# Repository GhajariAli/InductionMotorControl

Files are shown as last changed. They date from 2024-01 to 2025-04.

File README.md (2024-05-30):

# InductionMotorControl
Controlling 3 Phase AC Asynchronous Induction Motor

Check [This](https://github.com/GhajariAli/DCMotorControl) Repo for DC motor Control

<details>
<summary> Preparation </summary>
  
  <details>
    
  <summary> Motor Nameplate </summary>
  
  
  
  </details>
  
  <details>
    
  <summary> Designing the circuit </summary>
  
  I've Designed the control boad around this IC fro Infineon [IGCM04F60GAXKMA1](https://www.digikey.ca/en/products/detail/infineon-technologies/IGCM04F60GAXKMA1/5960098)
  
  Here is the video of testing the circuit and getting initial result:
  
   (https://www.youtube.com/shorts/fg0to3o2meA)
  
  So I designed a PCB to get things going Faster, you can find the KiCAD design and initial code to run the motor in [THIS](https://github.com/GhajariAli/InductionMotorControl/tree/FirstCurcuitDesign) branch
  
  
  
  
  
  
  
  </details>
  
  <details>
    
  <summary> Adding Encoder </summary>
  Induction Motors are usally not controlled by a closed loop using encoder but to validate and verify my own work I'd like to have and encoder on the shaft.
  
  [here](https://www.aliexpress.com/item/4000094589182.html?spm=a2g0o.order_list.order_list_main.56.1fdd1802ZbFUS8) is the encoder I've used : 
  
  (https://www.aliexpress.com/item/4000094589182.html?spm=a2g0o.order_list.order_list_main.51.55f218029jO34n)
  
  Below is what I've designed to mount the encoder, you'll find all 3D models in the same branch as mentioned in the circuit diagram section.
  
  
  
  
  
  Update: had to dessign and print the belt with TPU as it was not standard size turned out good:
  
  
  </details>

  <details>
    
  <summary> Testing the PCB </summary>
  PCB came very good. had to change couple resistors and design a base for it:
  
  

  
  
  and IT WORKS THE FIRST TRY!
  </details>
</details>

<details>
<summary> SPWM speed Control </summary>
  Here is the low and high side signals with only Hi side SPWM:

  

  and here is the final output 3phase
  
  

  this made the motor run smoother, current is now lower and it makes less noise.
  
  This was great but the curent of the motor was not sinusoidal at all.

  Terrible waveform:

  

  the reason is behind this picture
  
  
  
  so the high and low are not equal value. So it's required to add low side SPWM as well
  Here is the gate signals with all SPWM
  
  
  
  A Closer look
  
  

  Here is how the SPWM signals on the High side look after passing through a Filter:
  
  

  Now motor current is much more close to sinusoidal current
  
  

  here is how the syncronous speed, actual speed and slip looks like in a ramp to 50HZ and coast to stop. as you can see it's not great yet, need to source more voltage (currently only have 60VDC), I believe the V/F control can't go all the way to 50hz with 60 volt.

  

</details>

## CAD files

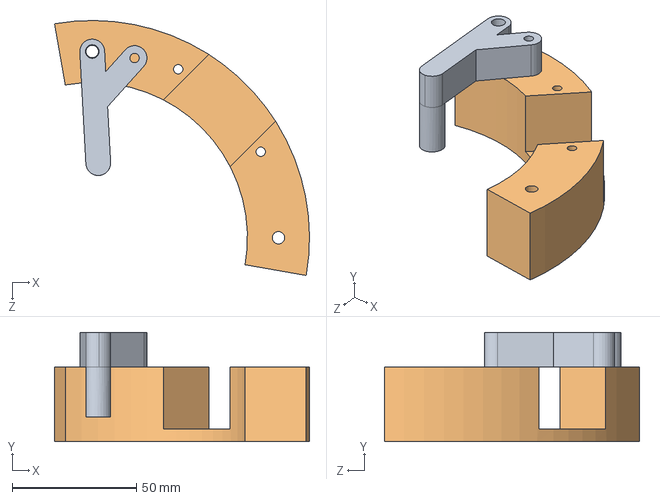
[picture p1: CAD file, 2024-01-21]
3D Models/Encoder.SLDASM
102.7 x 44.0 x 102.7 mm
Encoder Bracket
tensioner

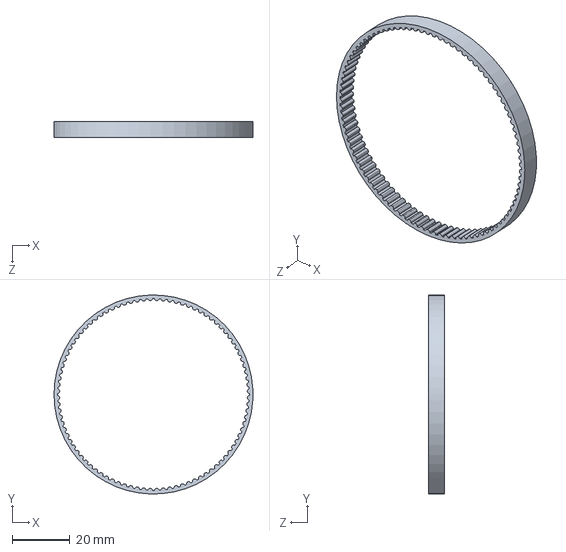
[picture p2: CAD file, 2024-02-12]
3D Models/belt.SLDPRT
69.0 x 69.0 x 5.50 mm

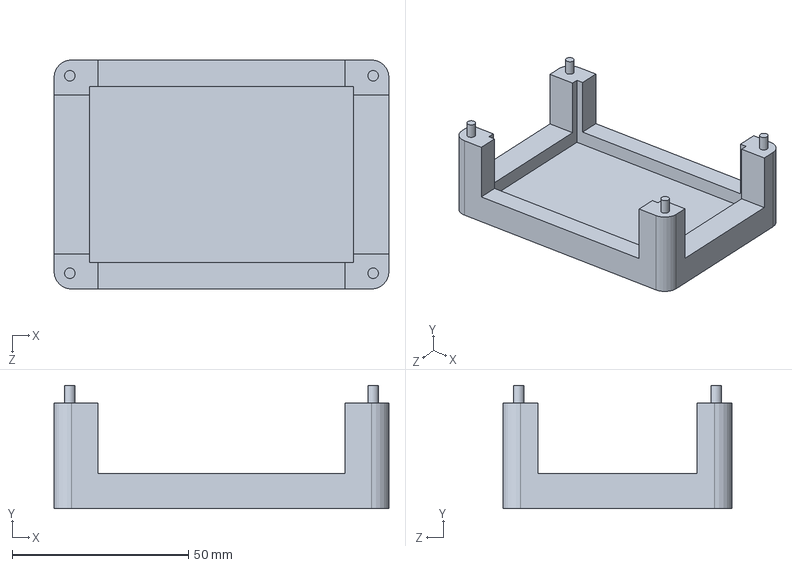
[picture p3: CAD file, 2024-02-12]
3D Models/base for board.SLDPRT
95.0 x 35.0 x 65.0 mm

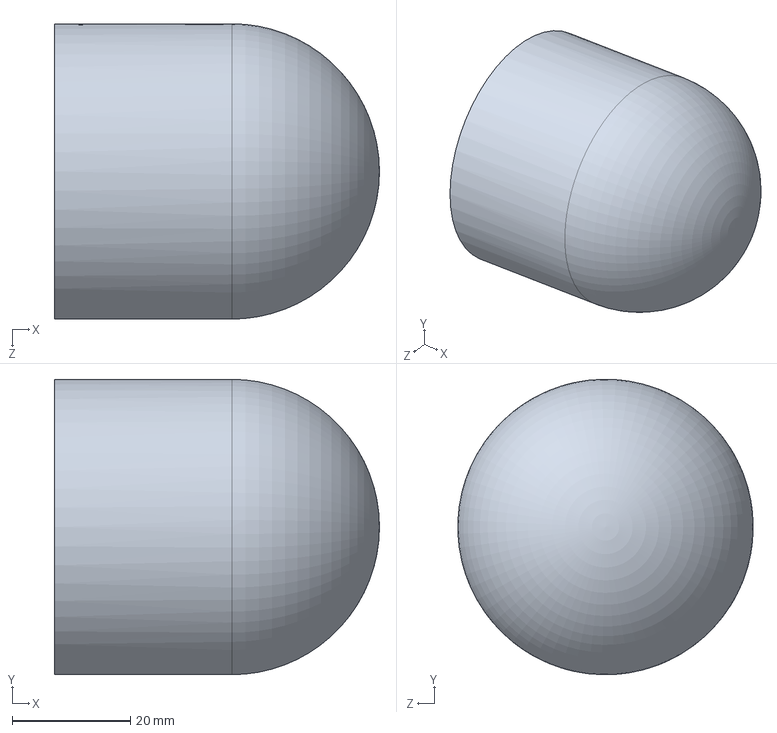
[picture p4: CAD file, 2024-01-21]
3D Models/ShaftFist.SLDPRT
55.0 x 50.0 x 50.0 mm

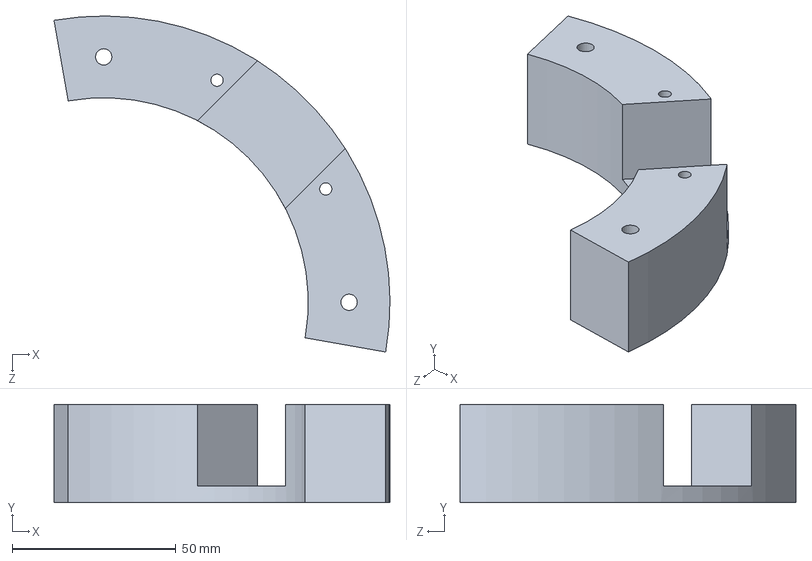
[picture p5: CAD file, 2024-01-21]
3D Models/Encoder Bracket.SLDPRT
102.7 x 30.0 x 102.7 mm

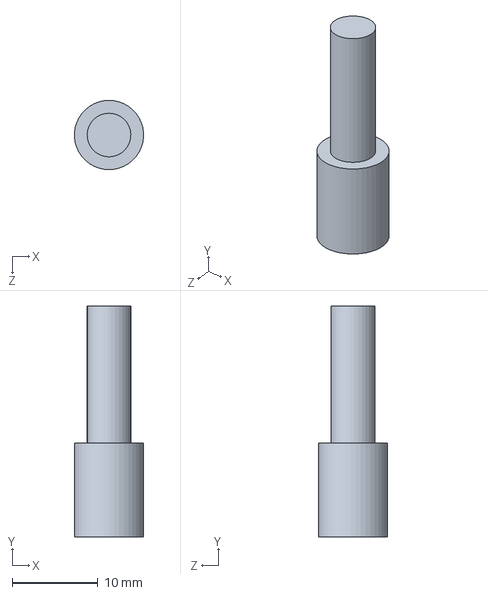
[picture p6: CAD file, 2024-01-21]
3D Models/Encoder Shaft.SLDPRT
8.08 x 27.0 x 8.10 mm

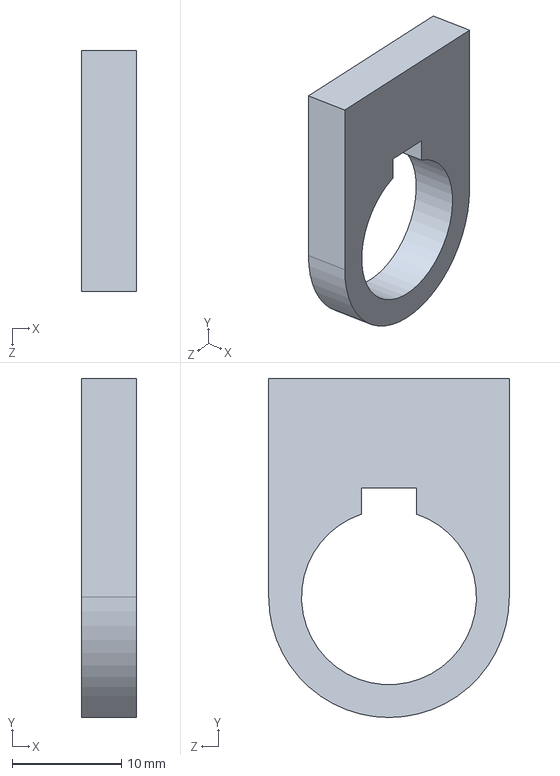
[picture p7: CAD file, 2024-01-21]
3D Models/ShaftFlag.SLDPRT
5.00 x 31.0 x 22.0 mm

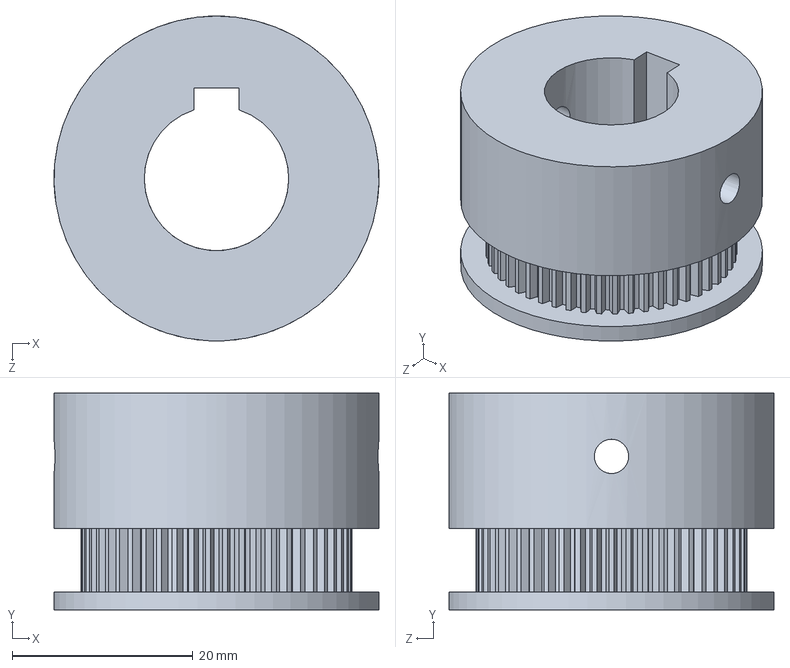
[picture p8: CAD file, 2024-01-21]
3D Models/motor pully.SLDPRT
36.0 x 24.0 x 36.0 mm

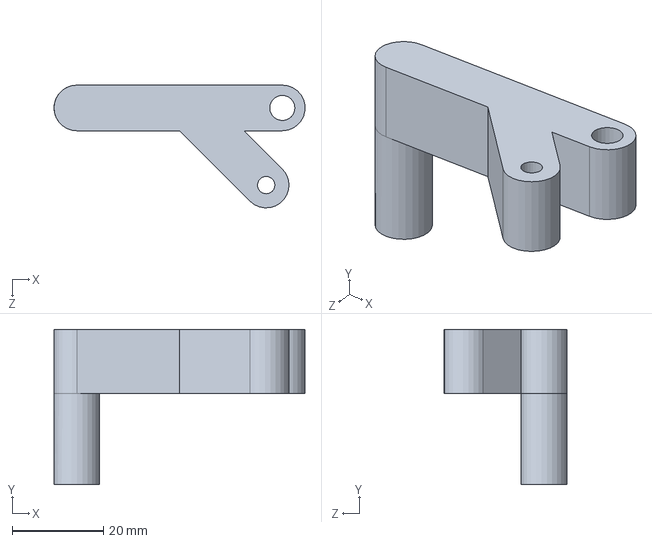
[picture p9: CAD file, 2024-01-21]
3D Models/tensioner.SLDPRT
55.0 x 34.0 x 26.9 mm

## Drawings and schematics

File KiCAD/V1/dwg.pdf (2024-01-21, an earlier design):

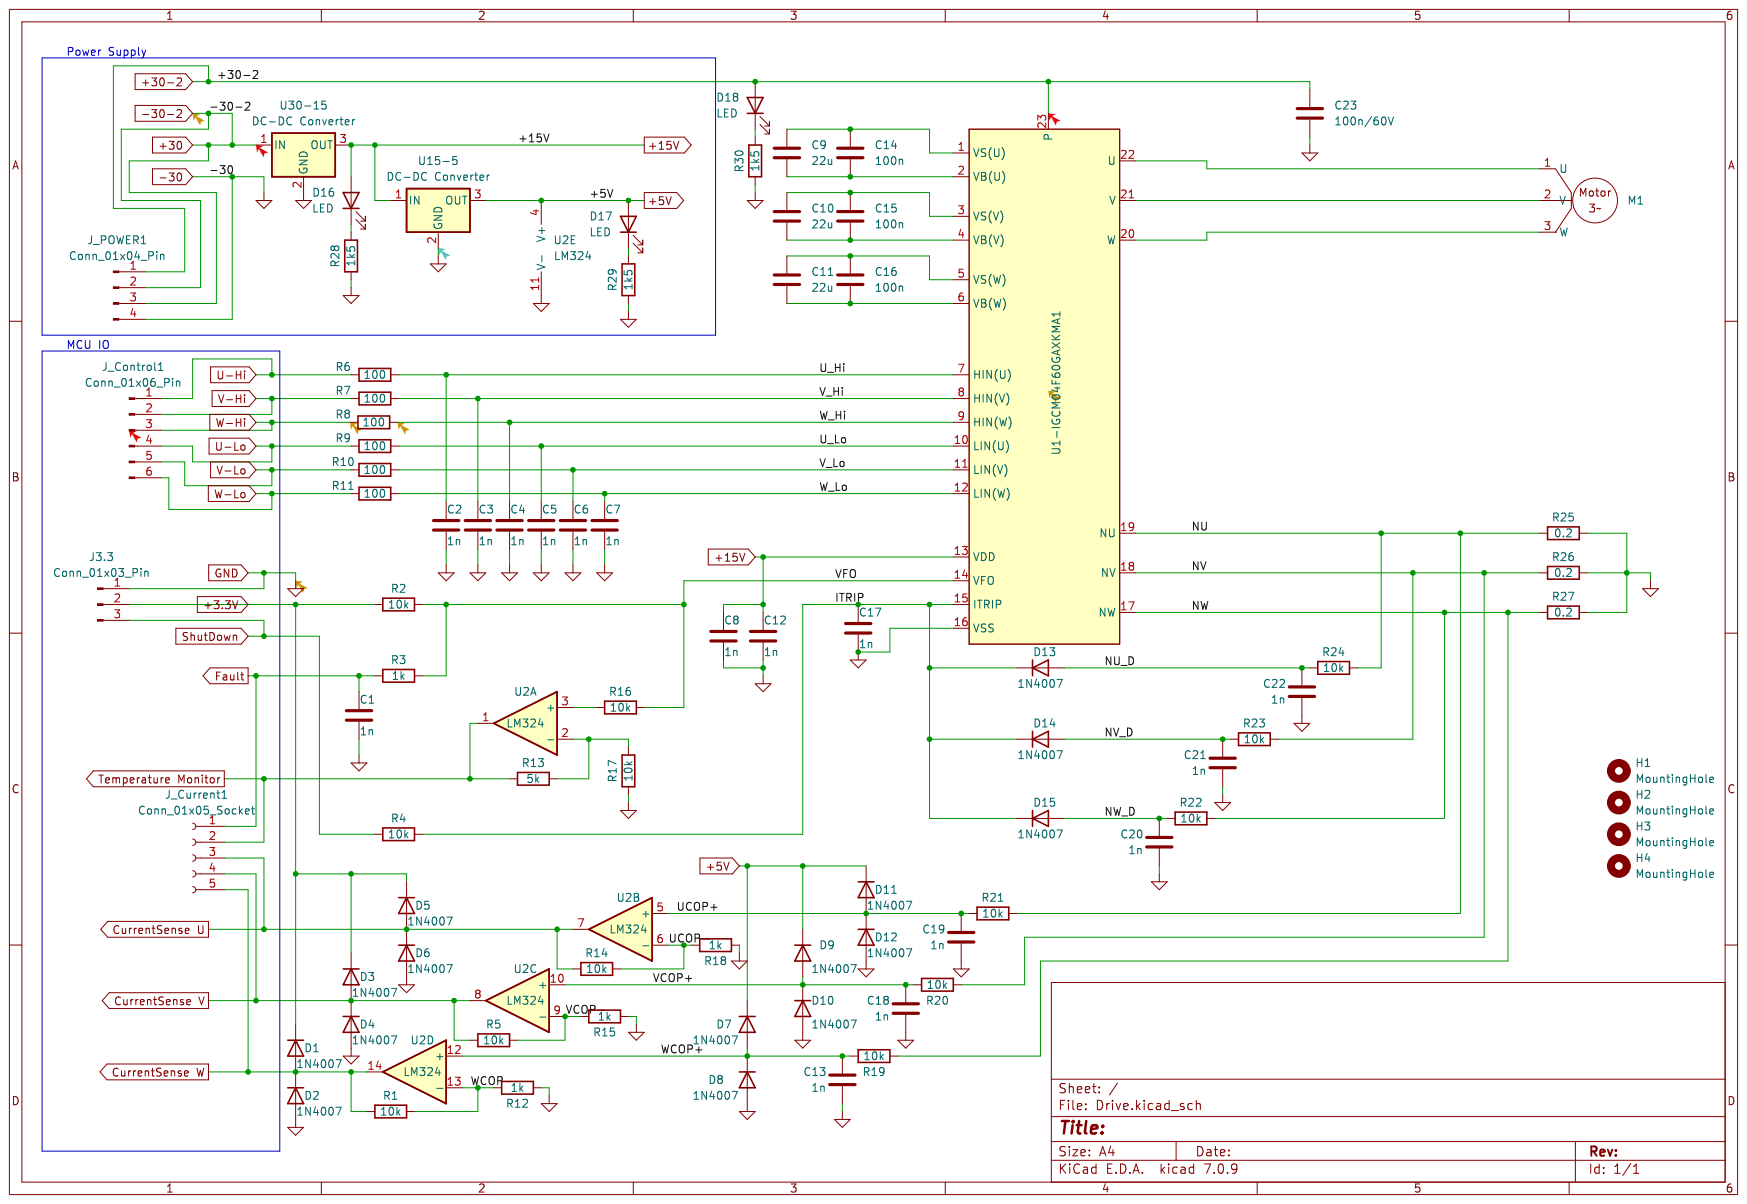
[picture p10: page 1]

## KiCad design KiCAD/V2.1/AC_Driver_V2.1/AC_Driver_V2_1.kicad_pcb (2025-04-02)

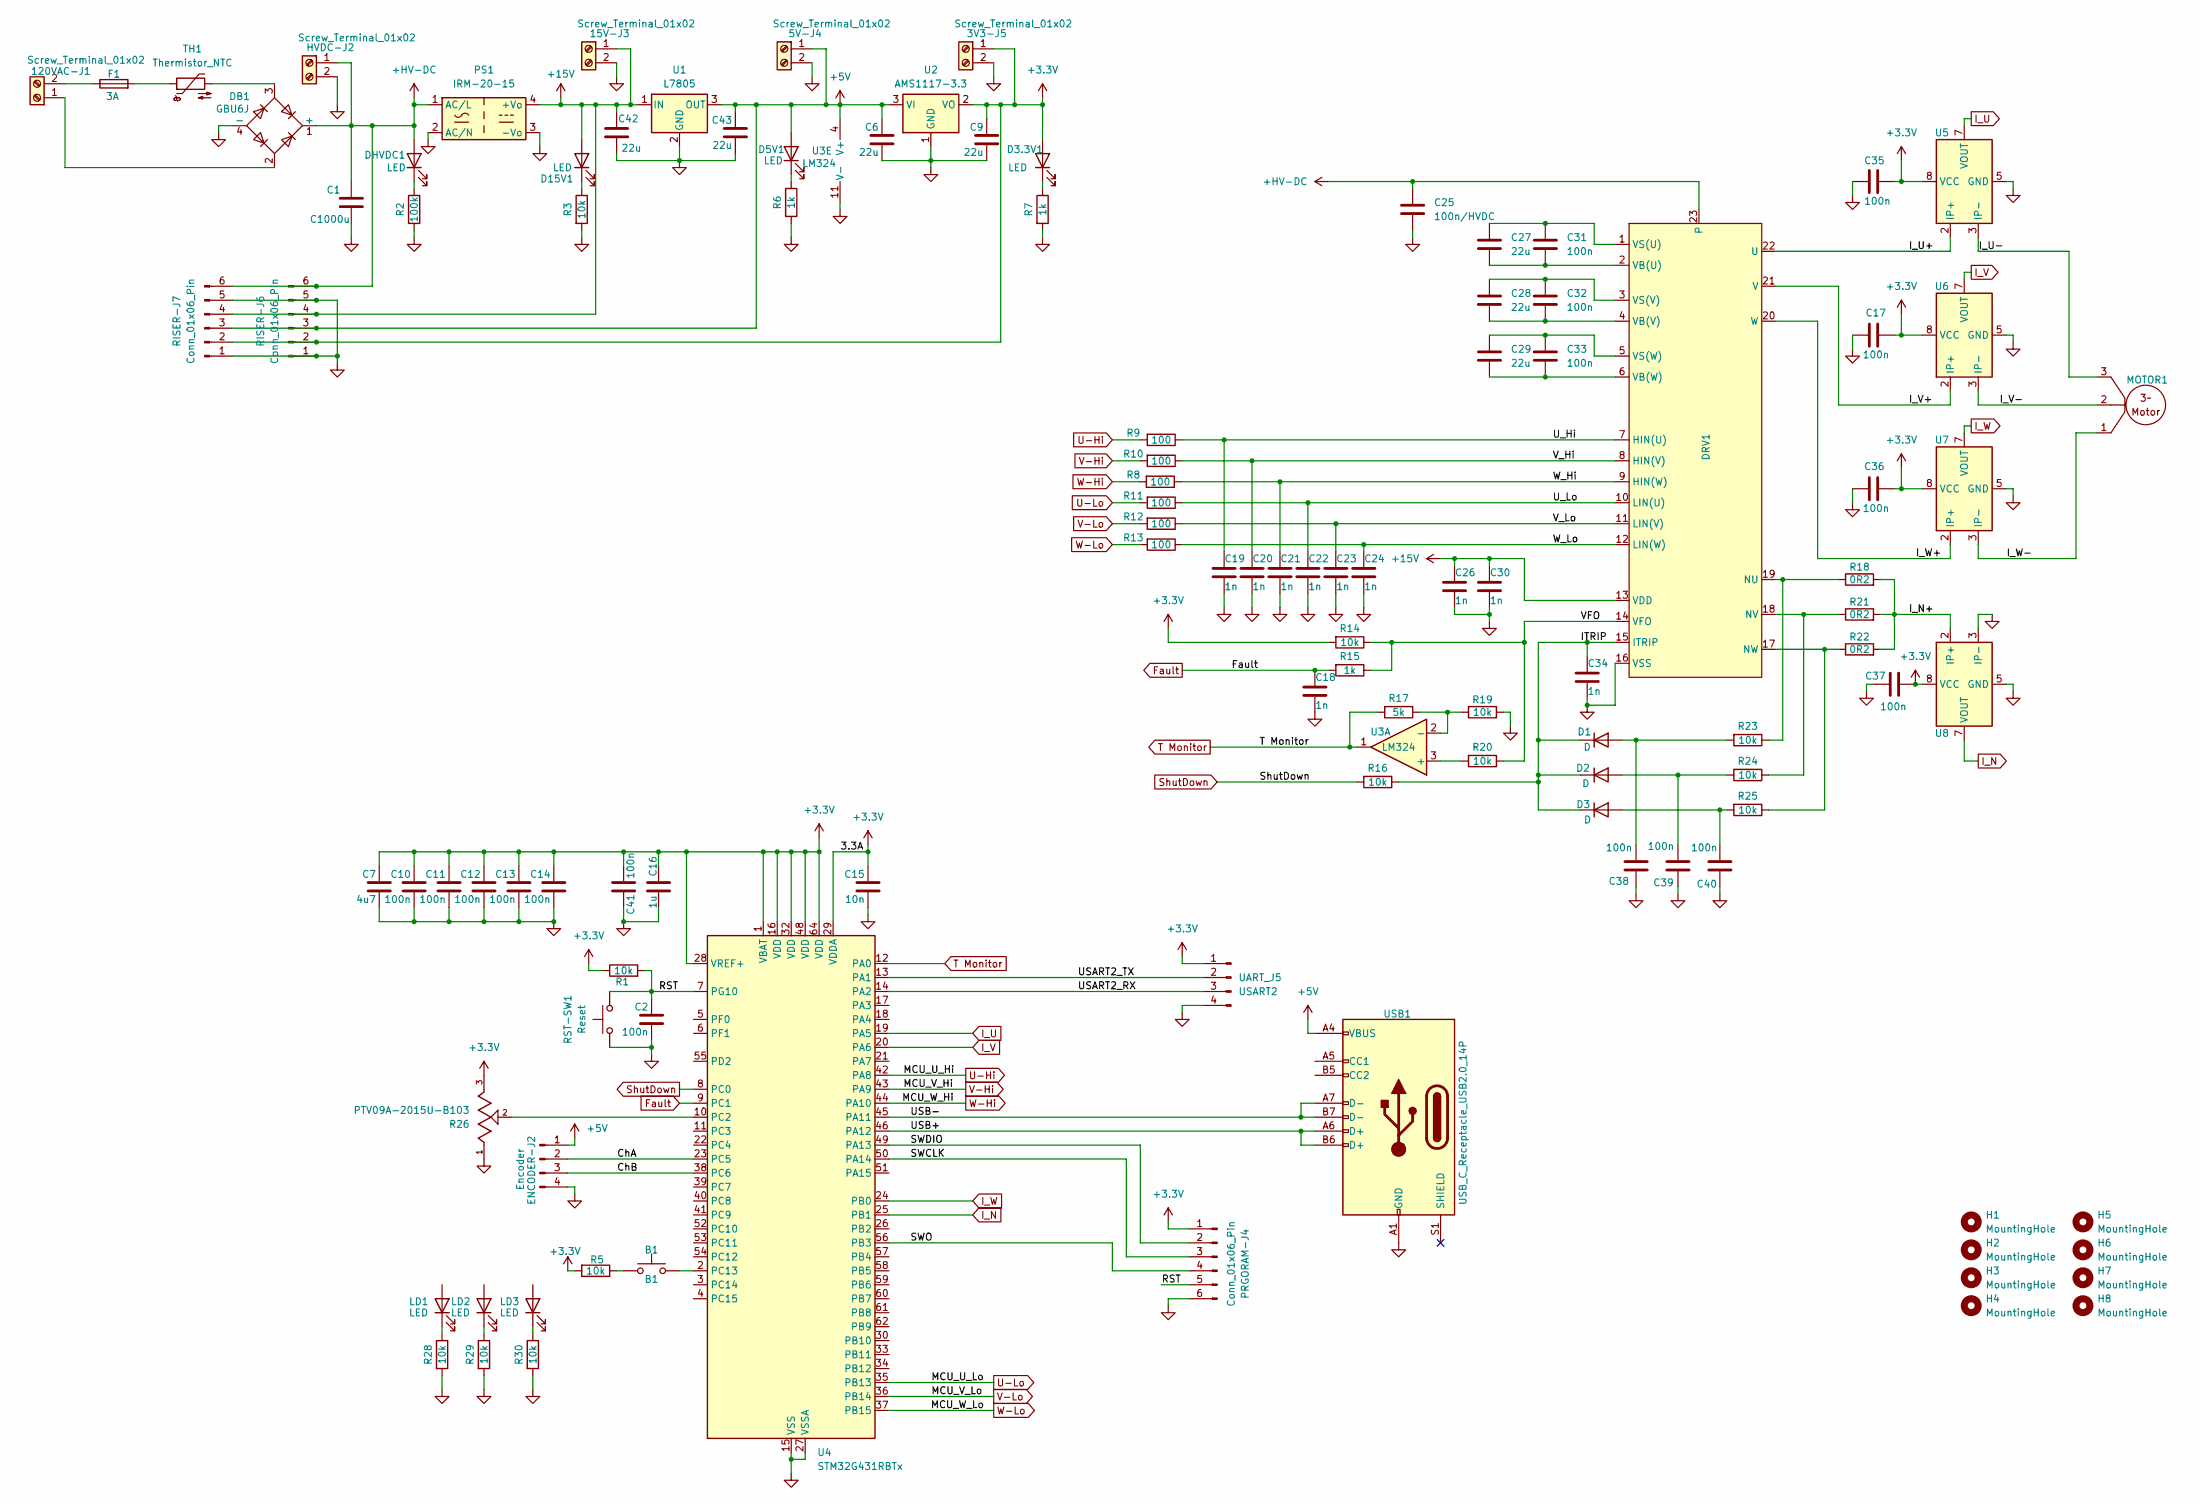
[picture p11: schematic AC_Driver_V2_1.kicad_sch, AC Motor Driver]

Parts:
3V3-J5, 5V-J4, 15V-J3, 120VAC-J1: Screw_Terminal_01x02; TerminalBlock_Phoenix_PT-1,5-2-5.0-H_1x02_P5.00mm_Horizontal
B1: B1; SW_Push_1TS009xxxx-xxxx-xxxx_6x6x5mm
C1: C1000u; CP_Radial_D22.0mm_P10.00mm_SnapIn
C2, C10, C11, C12, C13, C14, C17, C31, C32, C33, C35, C36, C37, C38, C39, C40, C41: 100n; C_0805_2012Metric
C6, C9, C42, C43: 22u; C_0805_2012Metric
C7: 4u7; C_0805_2012Metric
C15: 10n; C_0805_2012Metric
C16: 1u; C_0805_2012Metric
C18, C19, C20, C21, C22, C23, C24, C26, C30, C34: 1n; C_0805_2012Metric
C25: 100n/HVDC; C_0805_2012Metric
C27, C28, C29: 22u; C_Radial_D4.0mm_H7.0mm_P1.50mm
D1, D2, D3: D; L_1206_3216Metric
D3.3V1, D5V1, D15V1: LED; LED_0805_2012Metric
DB1: GBU6J; Diode_Bridge_Vishay_GBU
DHVDC1: LED; LED_0805_2012Metric
DRV1: IGCM04F60GAXKMA1
ENCODER-J2: Encoder; PinHeader_1x04_P2.54mm_Vertical
F1: 3A; L_2512_6332Metric
H1, H2, H3, H4, H5, H6, H7, H8: MountingHole; MountingHole_3.2mm_M3_Pad_Via
HVDC-J2: Screw_Terminal_01x02; TerminalBlock_Phoenix_PT-1,5-2-5.0-H_1x02_P5.00mm_Horizontal
LD1, LD2, LD3: LED; LED_0805_2012Metric
MOTOR1: TerminalBlock_Phoenix_PT-1,5-3-5.0-H_1x03_P5.00mm_Horizontal
PRGORAM-J4: Conn_01x06_Pin; PinHeader_1x06_P2.54mm_Vertical
PS1: IRM-20-15; Converter_ACDC_MeanWell_IRM-20-xx_THT
R1, R3, R5, R14, R16, R19, R20, R23, R24, R25, R28, R29, R30: 10k; R_0805_2012Metric
R2: 100k; R_0805_2012Metric
R6, R7, R15: 1k; R_0805_2012Metric
R8, R9, R10, R11, R12, R13: 100; R_0805_2012Metric
R17: 5k; R_0805_2012Metric
R18, R21, R22: 0R2; R_Axial_DIN0309_L9.0mm_D3.2mm_P2.54mm_Vertical
R26: PTV09A-2015U-B103; TRIM_PTV09A-2015U-B103; PARTREV 01/20
RISER-J6, RISER-J7: Conn_01x06_Pin; PinHeader_1x06_P2.54mm_Vertical
RST-SW1: Reset; SW_Push_1TS009xxxx-xxxx-xxxx_6x6x5mm
TH1: Thermistor_NTC; R_Axial_DIN0414_L11.9mm_D4.5mm_P7.62mm_Vertical
U1: L7805; TO-263-3_TabPin2
U2: AMS1117-3.3; SOT-223-3_TabPin2
U3: LM324; SSOP-14_5.3x6.2mm_P0.65mm
U4: STM32G431RBTx; LQFP-64_10x10mm_P0.5mm
U5, U6, U7, U8: ACS706xLC-05C; SOIC-8_3.9x4.9mm_P1.27mm
UART_J5: USART2; PinHeader_1x04_P2.54mm_Vertical
USB1: USB_C_Receptacle_USB2.0_14P; USB_C_Receptacle_GCT_USB4105-xx-A_16P_TopMnt_Horizontal

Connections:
+3.3V: 3V3-J5.1, C7.1, C9.1, C10.1, C11.1, C12.1, C13.1, C14.1, C15.1, C16.1, C17.1, C35.1, C36.1, C37.2, C41.2, D3.3V1.2 (A), PRGORAM-J4.1, R1.1, R5.2, R14.2, R26.3, RISER-J6.2, RISER-J7.2, U2.2 (VO), U4.1 (VBAT), U4.16 (VDD), U4.28 (VREF+), U4.29 (VDDA), U4.32 (VDD), U4.48 (VDD), U4.64 (VDD), U5.8 (VCC), U6.8 (VCC), U7.8 (VCC), U8.8 (VCC), UART_J5.1
+5V: 5V-J4.1, C6.1, C43.1, D5V1.2 (A), ENCODER-J2.1, RISER-J6.3, RISER-J7.3, U1.3 (OUT), U2.3 (VI), U3.4 (V+), USB1.A4 (VBUS), USB1.A9 (VBUS), USB1.B4 (VBUS), USB1.B9 (VBUS)
+15V: 15V-J3.1, C26.1, C30.1, C42.1, D15V1.2 (A), DRV1.13 (VDD), PS1.4 (+Vo), RISER-J6.4, RISER-J7.4, U1.1 (IN)
+HV-DC: C1.1, C25.1, DB1.1 (+), DHVDC1.2 (A), DRV1.23, HVDC-J2.1, PS1.1 (AC/L), RISER-J6.6, RISER-J7.6
/ChA: ENCODER-J2.2, U4.23 (PC5)
/ChB: ENCODER-J2.3, U4.38 (PC6)
/ITRIP: C34.1, D1.1 (K), D2.1 (K), D3.1 (K), DRV1.15 (ITRIP), R16.1
/I_N+: R18.2, R21.2, R22.2, U8.1 (IP+), U8.2 (IP+)
/I_U+: DRV1.22 (U), U5.1 (IP+), U5.2 (IP+)
/I_U-: MOTOR1.3 (W), U5.3 (IP-), U5.4 (IP-)
/I_V+: DRV1.21 (V), U6.1 (IP+), U6.2 (IP+)
/I_V-: MOTOR1.2 (V), U6.3 (IP-), U6.4 (IP-)
/I_W+: DRV1.20 (W), U7.1 (IP+), U7.2 (IP+)
/I_W-: MOTOR1.1 (U), U7.3 (IP-), U7.4 (IP-)
/RST: C2.1, PRGORAM-J4.5, R1.2, RST-SW1.2, U4.7 (PG10)
/SWCLK: PRGORAM-J4.3, U4.50 (PA14)
/SWDIO: PRGORAM-J4.2, U4.49 (PA13)
/SWO: PRGORAM-J4.4, U4.56 (PB3)
/USART2_RX: U4.14 (PA2), UART_J5.3
/USART2_TX: U4.13 (PA1), UART_J5.2
/USB+: U4.46 (PA12), USB1.A6 (D+), USB1.B6 (D+)
/USB-: U4.45 (PA11), USB1.A7 (D-), USB1.B7 (D-)
/U_Hi: C19.1, DRV1.7 (HIN(U)), R9.1
/U_Lo: C22.1, DRV1.10 (LIN(U)), R11.1
/VFO: DRV1.14 (VFO), R14.1, R15.1, R20.1
/V_Hi: C20.1, DRV1.8 (HIN(V)), R10.1
/V_Lo: C23.1, DRV1.11 (LIN(V)), R12.1
/W_Hi: C21.1, DRV1.9 (HIN(W)), R8.1
/W_Lo: C24.1, DRV1.12 (LIN(W)), R13.1
Fault: C18.1, R15.2, U4.9 (PC1)
GND: 3V3-J5.2, 5V-J4.2, 15V-J3.2, C1.2, C2.2, C6.2, C7.2, C9.2, C10.2, C11.2, C12.2, C13.2, C14.2, C15.2, C16.2, C17.2, C18.2, C19.2, C20.2, C21.2, C22.2, C23.2, C24.2, C25.2, C26.2, C30.2, C34.2, C35.2, C36.2, C37.1, C38.1, C39.1, C40.1, C41.1, C42.2, C43.2, DB1.4 (-), DRV1.16 (VSS), ENCODER-J2.4, HVDC-J2.2, PRGORAM-J4.6, PS1.2 (AC/N), PS1.3 (-Vo), R2.2, R3.2, R6.2, R7.2, R19.1, R26.1, R28.2, R29.2, R30.2, RISER-J6.1, RISER-J6.5, RISER-J7.1, RISER-J7.5, RST-SW1.1, U1.2 (GND), U2.1 (GND), U3.11 (V-), U4.15 (VSS), U4.27 (VSSA), U4.31 (VSS), U4.47 (VSS), U4.63 (VSS), U5.5 (GND), U6.5 (GND), U7.5 (GND), U8.3 (IP-), U8.4 (IP-), U8.5 (GND), UART_J5.4, USB1.A1 (GND), USB1.A12 (GND), USB1.B1 (GND), USB1.B12 (GND)
I_N: U4.25 (PB1), U8.7 (VOUT)
I_U: U4.19 (PA5), U5.7 (VOUT)
I_V: U4.20 (PA6), U6.7 (VOUT)
I_W: U4.24 (PB0), U7.7 (VOUT)
unnamed: 120VAC-J1.1, DB1.2
unnamed: 120VAC-J1.2, F1.1
unnamed: B1.1, R5.1
unnamed: C38.2, D1.2 (A), R23.2
unnamed: C39.2, D2.2 (A), R24.2
unnamed: C40.2, D3.2 (A), R25.2
unnamed: D3.3V1.1 (K), R7.1
unnamed: D5V1.1 (K), R6.1
unnamed: D15V1.1 (K), R3.1
unnamed: DB1.3, TH1.2
unnamed: DHVDC1.1 (K), R2.1
unnamed: DRV1.19 (NU), R18.1, R23.1
unnamed: DRV1.18 (NV), R21.1, R24.1
unnamed: DRV1.17 (NW), R22.1, R25.1
unnamed: C27.2, C31.2, DRV1.2 (VB(U))
unnamed: C28.2, C32.2, DRV1.4 (VB(V))
unnamed: C29.2, C33.2, DRV1.6 (VB(W))
unnamed: C27.1, C31.1, DRV1.1 (VS(U))
unnamed: C28.1, C32.1, DRV1.3 (VS(V))
unnamed: C29.1, C33.1, DRV1.5 (VS(W))
unnamed: F1.2, TH1.1
unnamed: LD1.1 (K), R28.1
unnamed: LD2.1 (K), R29.1
unnamed: LD3.1 (K), R30.1
unnamed: R20.2, U3.3 (+)
unnamed: R17.1, R19.2, U3.2 (-)
unnamed: R26.2, U4.10 (PC2)
unnamed: B1.2, U4.2 (PC13)
ShutDown: R16.2, U4.8 (PC0)
T Monitor: R17.2, U3.1, U4.12 (PA0)
U-Hi: R9.2, U4.42 (PA8)
U-Lo: R11.2, U4.35 (PB13)
V-Hi: R10.2, U4.43 (PA9)
V-Lo: R12.2, U4.36 (PB14)
W-Hi: R8.2, U4.44 (PA10)
W-Lo: R13.2, U4.37 (PB15)

Board: 4 copper layers, 112 parts (13 on the bottom side), 71 nets, no tracks yet.

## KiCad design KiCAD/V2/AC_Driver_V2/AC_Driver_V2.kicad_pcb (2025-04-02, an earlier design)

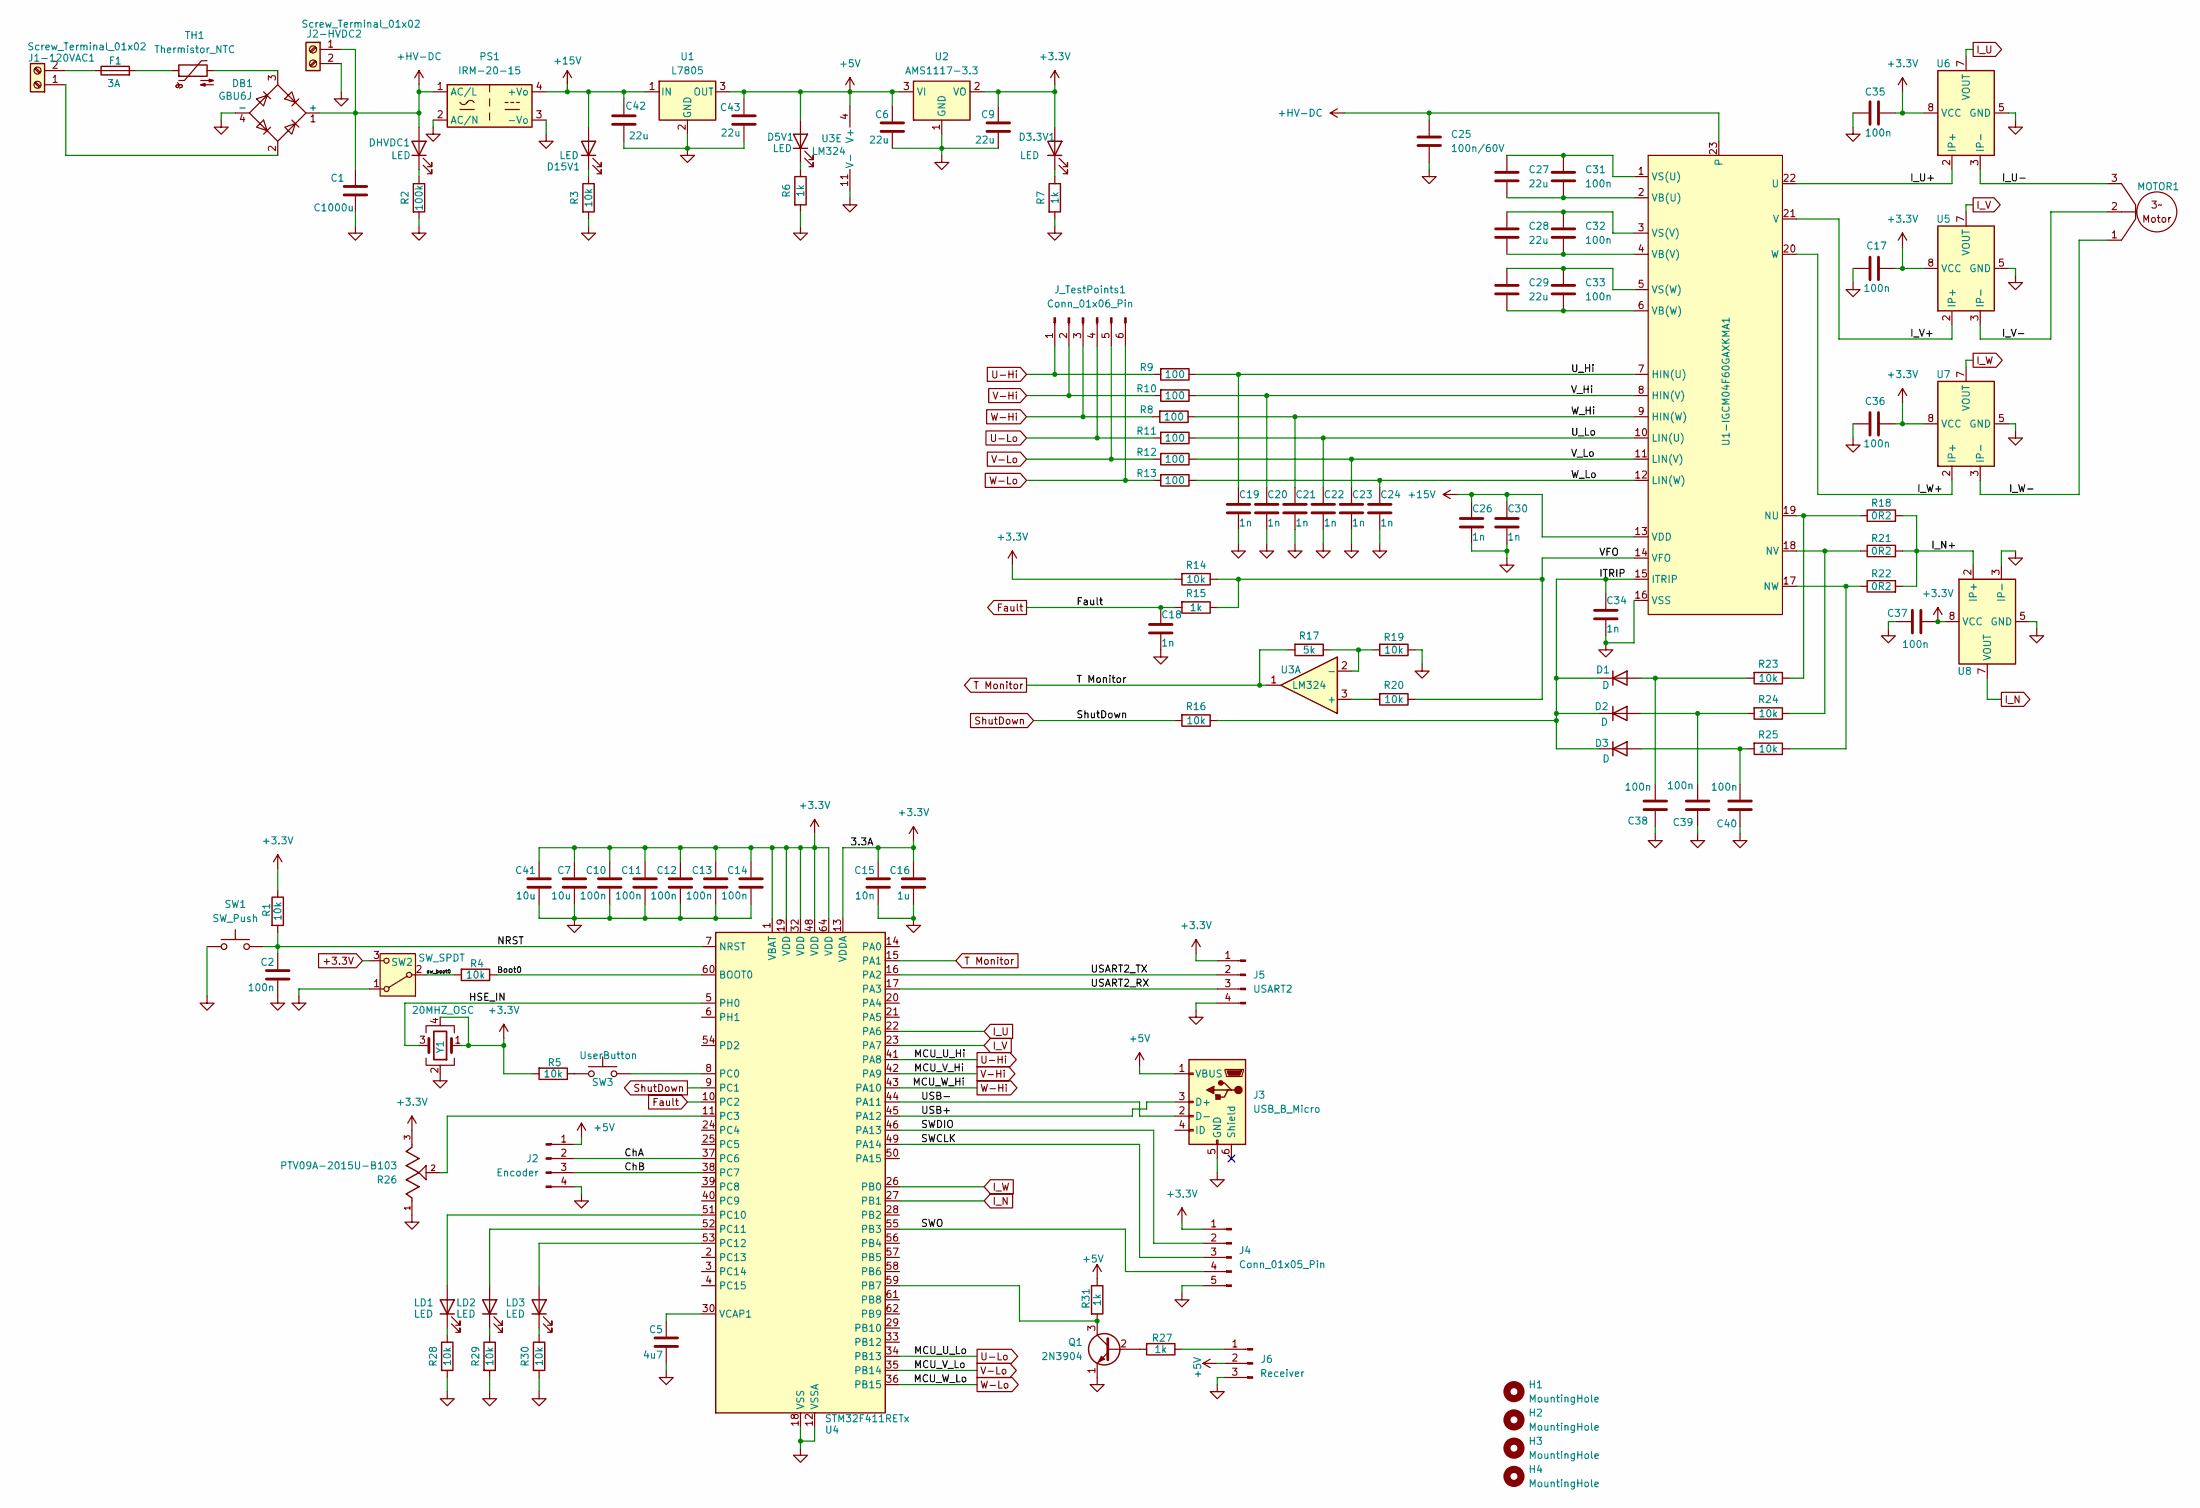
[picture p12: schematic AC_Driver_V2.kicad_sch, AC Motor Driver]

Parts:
C1: C1000u; CP_Radial_D22.0mm_P10.00mm_SnapIn
C2, C10, C11, C12, C13, C14, C17, C31, C32, C33, C35, C36, C37, C38, C39, C40: 100n; C_0805_2012Metric
C5: 4u7; C_0805_2012Metric
C6, C9, C42, C43: 22u; C_0805_2012Metric
C7, C41: 10u; C_0805_2012Metric
C15: 10n; C_0805_2012Metric
C16: 1u; C_0805_2012Metric
C18, C19, C20, C21, C22, C23, C24, C26, C30, C34: 1n; C_0805_2012Metric
C25: 100n/60V; C_0805_2012Metric
C27, C28, C29: 22u; C_Radial_D4.0mm_H7.0mm_P1.50mm
D1, D2, D3: D; L_1206_3216Metric
D3.3V1, D5V1, D15V1: LED; LED_0805_2012Metric
DB1: GBU6J; Diode_Bridge_Vishay_GBU
DHVDC1: LED; LED_0805_2012Metric
F1: 3A; L_2512_6332Metric
H1, H2, H3, H4: MountingHole; MountingHole_3.2mm_M3_Pad_Via
J1-120VAC1, J2-HVDC2: Screw_Terminal_01x02; TerminalBlock_Phoenix_PT-1,5-2-5.0-H_1x02_P5.00mm_Horizontal
J2: Encoder; PinHeader_1x04_P2.54mm_Vertical
J3: USB_B_Micro; USB_Micro-B_Amphenol_10103594-0001LF_Horizontal
J4: Conn_01x05_Pin; PinHeader_1x05_P2.54mm_Vertical
J5: USART2; PinHeader_1x04_P2.54mm_Vertical
J6: Receiver; PinHeader_1x03_P2.54mm_Vertical
J_TestPoints1: Conn_01x06_Pin; PinHeader_1x06_P2.54mm_Vertical
LD1, LD2, LD3: LED; LED_0805_2012Metric
MOTOR1: TerminalBlock_Phoenix_PT-1,5-3-5.0-H_1x03_P5.00mm_Horizontal
PS1: IRM-20-15; Converter_ACDC_MeanWell_IRM-20-xx_THT
Q1: 2N3904; TO-92_Inline
R1, R3, R4, R5, R14, R16, R19, R20, R23, R24, R25, R28, R29, R30: 10k; R_0805_2012Metric
R2: 100k; R_0805_2012Metric
R6, R7, R15, R27, R31: 1k; R_0805_2012Metric
R8, R9, R10, R11, R12, R13: 100; R_0805_2012Metric
R17: 5k; R_0805_2012Metric
R18, R21, R22: 0R2; R_Axial_DIN0309_L9.0mm_D3.2mm_P2.54mm_Vertical
R26: PTV09A-2015U-B103; TRIM_PTV09A-2015U-B103; PARTREV 01/20
SW1: SW_Push; SW_Push_1TS009xxxx-xxxx-xxxx_6x6x5mm
SW2: SW_SPDT; SW_SPDT_PCM12
SW3: UserButton; SW_Push_1TS009xxxx-xxxx-xxxx_6x6x5mm
TH1: Thermistor_NTC; R_Axial_DIN0414_L11.9mm_D4.5mm_P7.62mm_Vertical
U1: L7805; TO-263-3_TabPin2
U1-IGCM04F60GAXKMA1: IGCM04F60GAXKMA1
U2: AMS1117-3.3; SOT-223-3_TabPin2
U3: LM324; SSOP-14_5.3x6.2mm_P0.65mm
U4: STM32F411RETx; LQFP-64_10x10mm_P0.5mm
U5, U6, U7, U8: ACS706xLC-05C; SOIC-8_3.9x4.9mm_P1.27mm
Y1: 20MHZ_OSC; Crystal_SMD_Abracon_ABM3C-4Pin_5.0x3.2mm

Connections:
+3.3V: C7.1, C9.1, C10.1, C11.1, C12.1, C13.1, C14.1, C15.1, C16.1, C17.1, C35.1, C36.1, C37.2, C41.1, D3.3V1.2 (A), J4.1, J5.1, R1.1, R5.2, R14.2, R26.3, SW2.3 (C), U2.2 (VO), U4.1 (VBAT), U4.13 (VDDA), U4.19 (VDD), U4.32 (VDD), U4.48 (VDD), U4.64 (VDD), U5.8 (VCC), U6.8 (VCC), U7.8 (VCC), U8.8 (VCC), Y1.1, Y1.4; also elsewhere on the board
+5V: C6.1, C43.1, D5V1.2 (A), J2.1, J3.1 (VBUS), J6.2, R31.1, U1.3 (OUT), U2.3 (VI), U3.4 (V+); also elsewhere on the board
+15V: C26.1, C30.1, C42.1, D15V1.2 (A), PS1.4 (+Vo), U1.1 (IN), U1-IGCM04F60GAXKMA1.13 (VDD); also elsewhere on the board
+HV-DC: C1.1, C25.1, DB1.1 (+), DHVDC1.2 (A), J2-HVDC2.1, PS1.1 (AC/L), U1-IGCM04F60GAXKMA1.23; also elsewhere on the board
/Boot0: R4.1, U4.60 (BOOT0)
/ChA: J2.2, U4.37 (PC6)
/ChB: J2.3, U4.38 (PC7)
/HSE_IN: U4.5 (PH0), Y1.3
/ITRIP: C34.1, D1.1 (K), D2.1 (K), D3.1 (K), R16.1, U1-IGCM04F60GAXKMA1.15 (ITRIP)
/I_N+: R18.2, R21.2, R22.2, U8.1 (IP+), U8.2 (IP+)
/I_U+: U1-IGCM04F60GAXKMA1.22 (U), U6.1 (IP+), U6.2 (IP+)
/I_U-: MOTOR1.3 (W), U6.3 (IP-), U6.4 (IP-)
/I_V+: U1-IGCM04F60GAXKMA1.21 (V), U5.1 (IP+), U5.2 (IP+)
/I_V-: MOTOR1.2 (V), U5.3 (IP-), U5.4 (IP-)
/I_W+: U1-IGCM04F60GAXKMA1.20 (W), U7.1 (IP+), U7.2 (IP+)
/I_W-: MOTOR1.1 (U), U7.3 (IP-), U7.4 (IP-)
/NRST: C2.1, R1.2, SW1.2, U4.7 (NRST)
/SWCLK: J4.3, U4.49 (PA14)
/SWDIO: J4.2, U4.46 (PA13)
/SWO: J4.4, U4.55 (PB3)
/USART2_RX: J5.3, U4.17 (PA3)
/USART2_TX: J5.2, U4.16 (PA2)
/USB+: J3.3 (D+), U4.45 (PA12)
/USB-: J3.2 (D-), U4.44 (PA11)
/U_Hi: C19.1, R9.1, U1-IGCM04F60GAXKMA1.7 (HIN(U))
/U_Lo: C22.1, R11.1, U1-IGCM04F60GAXKMA1.10 (LIN(U))
/VFO: R14.1, R15.1, R20.1, U1-IGCM04F60GAXKMA1.14 (VFO)
/V_Hi: C20.1, R10.1, U1-IGCM04F60GAXKMA1.8 (HIN(V))
/V_Lo: C23.1, R12.1, U1-IGCM04F60GAXKMA1.11 (LIN(V))
/W_Hi: C21.1, R8.1, U1-IGCM04F60GAXKMA1.9 (HIN(W))
/W_Lo: C24.1, R13.1, U1-IGCM04F60GAXKMA1.12 (LIN(W))
/sw_boot0: R4.2, SW2.2 (B)
Fault: C18.1, R15.2, U4.10 (PC2)
GND: C1.2, C2.2, C5.2, C6.2, C7.2, C9.2, C10.2, C11.2, C12.2, C13.2, C14.2, C15.2, C16.2, C17.2, C18.2, C19.2, C20.2, C21.2, C22.2, C23.2, C24.2, C25.2, C26.2, C30.2, C34.2, C35.2, C36.2, C37.1, C38.1, C39.1, C40.1, C41.2, C42.2, C43.2, DB1.4 (-), J2.4, J2-HVDC2.2, J3.5 (GND), J4.5, J5.4, J6.3, PS1.2 (AC/N), PS1.3 (-Vo), Q1.1 (E), R2.2, R3.2, R6.2, R7.2, R19.1, R26.1, R28.2, R29.2, R30.2, SW1.1, SW2.1 (A), U1.2 (GND), U1-IGCM04F60GAXKMA1.16 (VSS), U2.1 (GND), U3.11 (V-), U4.12 (VSSA), U4.18 (VSS), U4.31 (VSS), U4.47 (VSS), U4.63 (VSS), U5.5 (GND), U6.5 (GND), U7.5 (GND), U8.3 (IP-), U8.4 (IP-), U8.5 (GND), Y1.2; also elsewhere on the board
I_N: U4.27 (PB1), U8.7 (VOUT); also elsewhere on the board
I_U: U4.22 (PA6), U6.7 (VOUT); also elsewhere on the board
I_V: U4.23 (PA7), U5.7 (VOUT); also elsewhere on the board
I_W: U4.26 (PB0), U7.7 (VOUT); also elsewhere on the board
unnamed: C38.2, D1.2 (A), R23.2
unnamed: C39.2, D2.2 (A), R24.2
unnamed: C40.2, D3.2 (A), R25.2
unnamed: D3.3V1.1 (K), R7.1
unnamed: D5V1.1 (K), R6.1
unnamed: D15V1.1 (K), R3.1
unnamed: DB1.3, TH1.2
unnamed: DHVDC1.1 (K), R2.1
unnamed: F1.2, TH1.1
unnamed: DB1.2, J1-120VAC1.1
unnamed: F1.1, J1-120VAC1.2
unnamed: J6.1, R27.1
unnamed: LD1.2 (A), U4.51 (PC10)
unnamed: LD1.1 (K), R28.1
unnamed: LD2.2 (A), U4.52 (PC11)
unnamed: LD2.1 (K), R29.1
unnamed: LD3.2 (A), U4.53 (PC12)
unnamed: LD3.1 (K), R30.1
unnamed: Q1.2 (B), R27.2
unnamed: Q1.3 (C), R31.2, U4.59 (PB7)
unnamed: R5.1, SW3.1
unnamed: R18.1, R23.1, U1-IGCM04F60GAXKMA1.19 (NU)
unnamed: R21.1, R24.1, U1-IGCM04F60GAXKMA1.18 (NV)
unnamed: R22.1, R25.1, U1-IGCM04F60GAXKMA1.17 (NW)
unnamed: C27.2, C31.2, U1-IGCM04F60GAXKMA1.2 (VB(U))
unnamed: C28.2, C32.2, U1-IGCM04F60GAXKMA1.4 (VB(V))
unnamed: C29.2, C33.2, U1-IGCM04F60GAXKMA1.6 (VB(W))
unnamed: C27.1, C31.1, U1-IGCM04F60GAXKMA1.1 (VS(U))
unnamed: C28.1, C32.1, U1-IGCM04F60GAXKMA1.3 (VS(V))
unnamed: C29.1, C33.1, U1-IGCM04F60GAXKMA1.5 (VS(W))
unnamed: R20.2, U3.3 (+)
unnamed: R17.1, R19.2, U3.2 (-)
unnamed: SW3.2, U4.8 (PC0)
unnamed: R26.2, U4.11 (PC3)
unnamed: C5.1, U4.30 (VCAP1)
ShutDown: R16.2, U4.9 (PC1)
T Monitor: R17.2, U3.1, U4.15 (PA1)
U-Hi: J_TestPoints1.1, R9.2, U4.41 (PA8)
U-Lo: J_TestPoints1.4, R11.2, U4.34 (PB13)
V-Hi: J_TestPoints1.2, R10.2, U4.42 (PA9)
V-Lo: J_TestPoints1.5, R12.2, U4.35 (PB14)
W-Hi: J_TestPoints1.3, R8.2, U4.43 (PA10)
W-Lo: J_TestPoints1.6, R13.2, U4.36 (PB15)

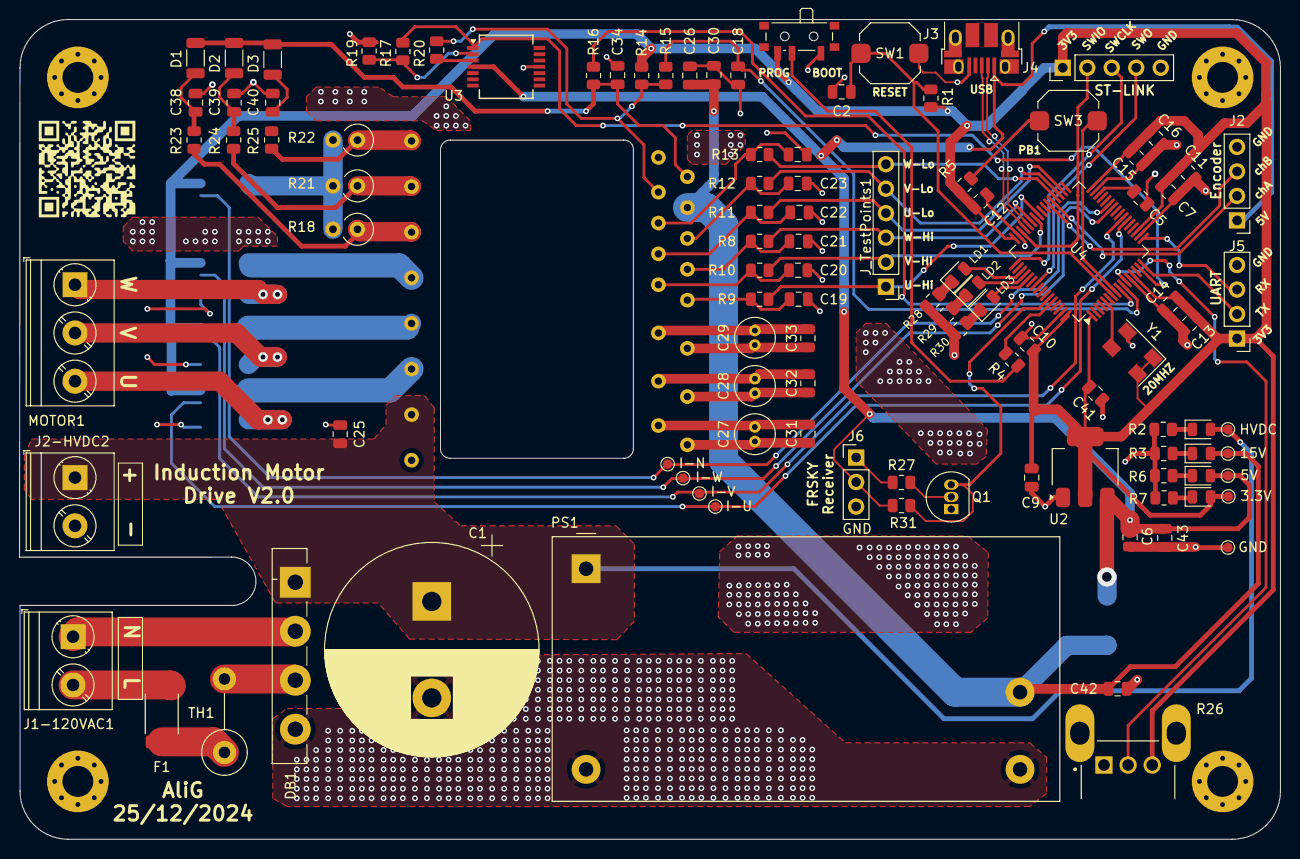
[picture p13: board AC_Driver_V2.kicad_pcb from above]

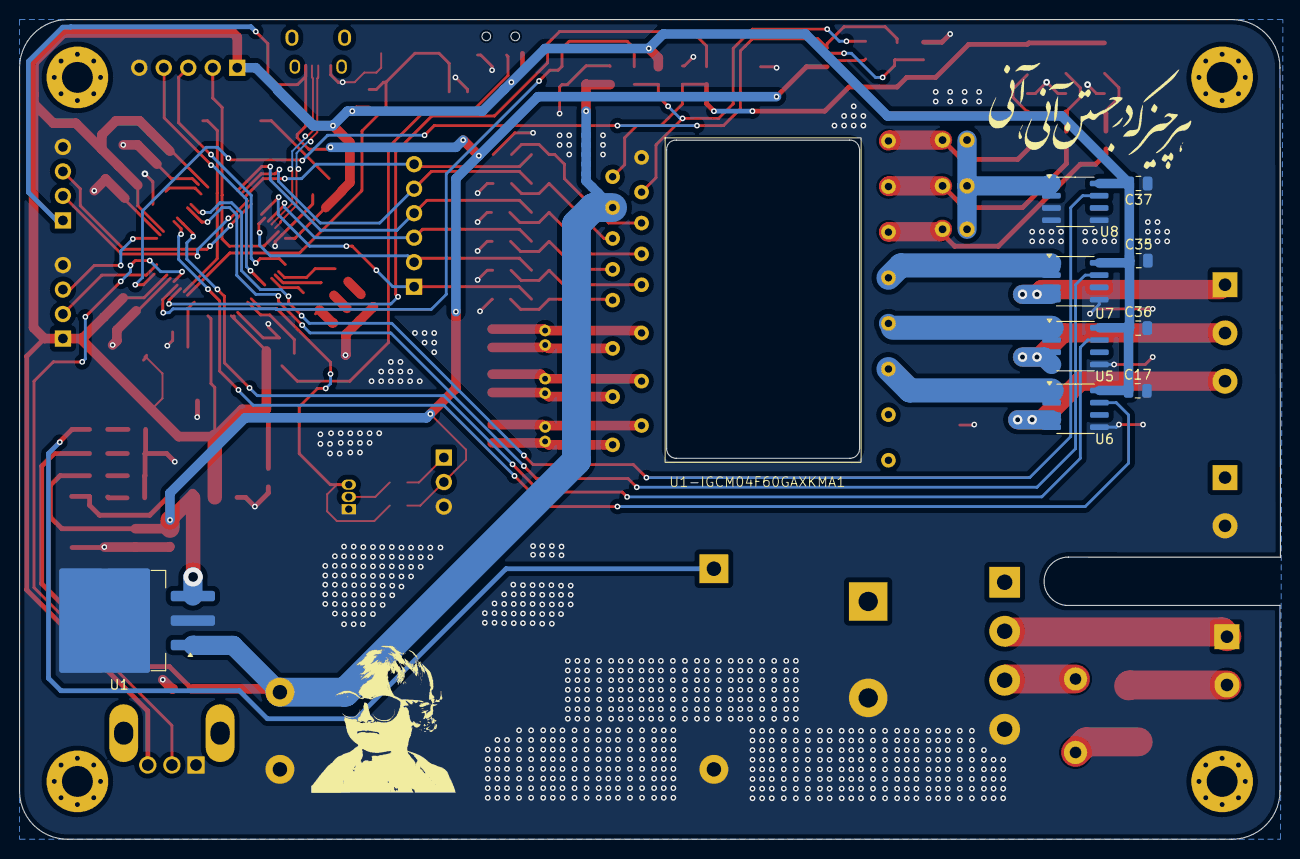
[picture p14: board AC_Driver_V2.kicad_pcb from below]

Board: 2 copper layers, 130.8 x 85.0 mm, 121 parts (10 on the bottom side), 81 nets.

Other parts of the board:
3.3V, 5V, 15V: TestPoint_Pad_D1.0mm
GND: TestPoint_Pad_D1.0mm
HVDC: TestPoint_Pad_D1.0mm
I-N: TestPoint_Pad_D1.0mm
I-U: TestPoint_Pad_D1.0mm
I-V: TestPoint_Pad_D1.0mm
I-W: TestPoint_Pad_D1.0mm

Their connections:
+3.3V: 3.3V.1; also elsewhere on the board
+5V: 5V.1; also elsewhere on the board
+15V: 15V.1; also elsewhere on the board
+HV-DC: HVDC.1; also elsewhere on the board
GND: GND.1; also elsewhere on the board
I_N: I-N.1; also elsewhere on the board
I_U: I-U.1; also elsewhere on the board
I_V: I-V.1; also elsewhere on the board
I_W: I-W.1; also elsewhere on the board

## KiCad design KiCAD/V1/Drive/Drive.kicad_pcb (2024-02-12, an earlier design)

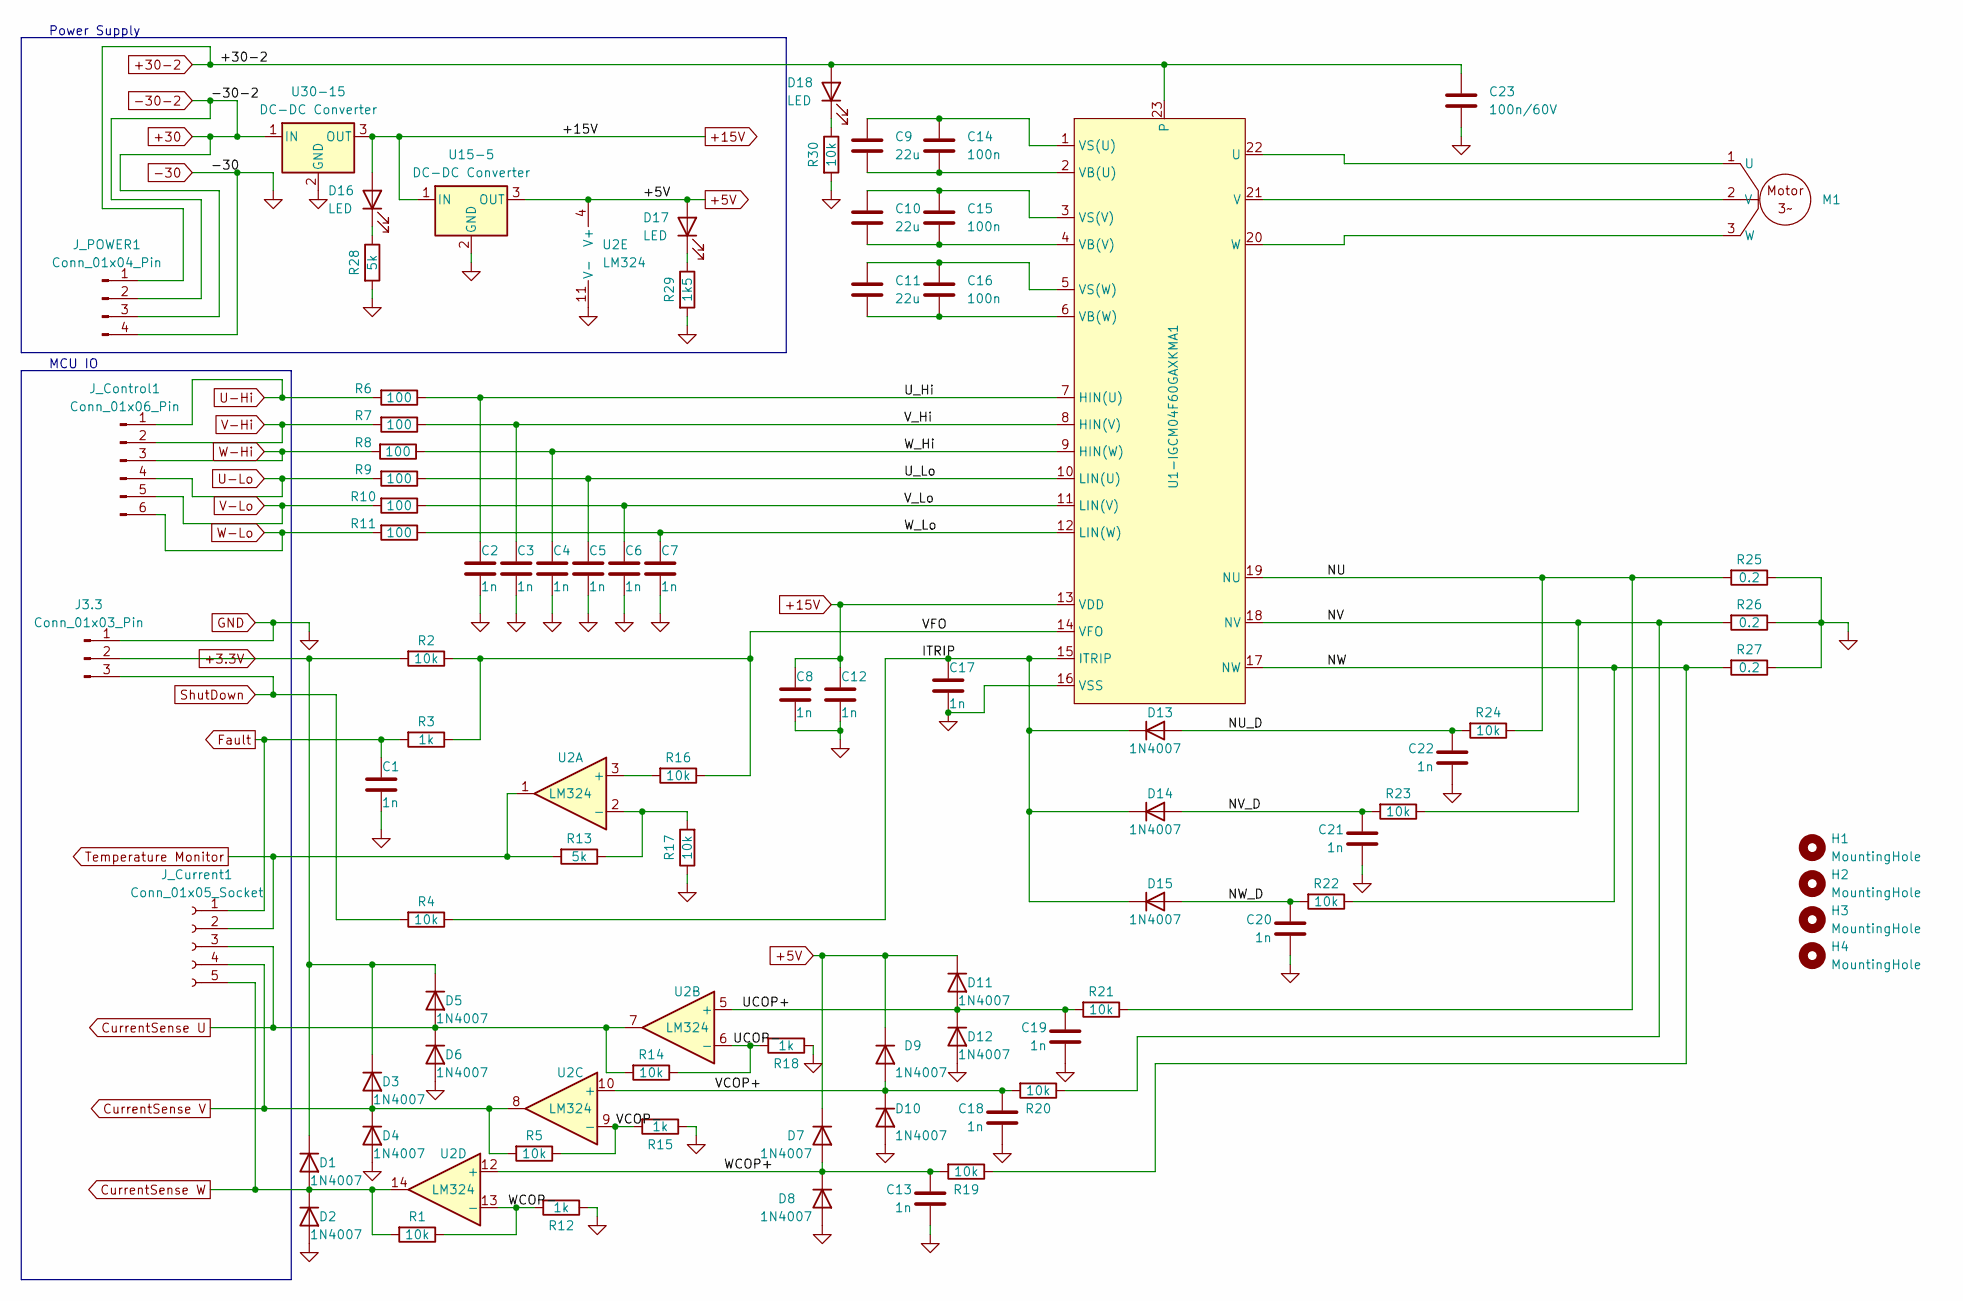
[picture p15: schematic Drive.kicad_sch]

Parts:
C1, C2, C3, C4, C5, C6, C7, C8, C12, C13, C17, C18, C19, C20, C21, C22: 1n; C_1206_3216Metric
C9, C10, C11: 22u; C_Radial_D4.0mm_H7.0mm_P1.50mm
C14, C15, C16: 100n; C_1206_3216Metric
C23: 100n/60V; C_1206_3216Metric
D1, D2, D3, D4, D5, D6, D7, D8, D9, D10, D11, D12, D13, D14, D15: 1N4007; D_SOD-323
D16, D17, D18: LED; LED_1206_3216Metric
H1, H2, H3, H4: MountingHole; MountingHole_3.5mm
J3.3: Conn_01x03_Pin; PinHeader_1x03_P2.54mm_Vertical
J_Control1: Conn_01x06_Pin; PinHeader_1x06_P2.54mm_Vertical
J_Current1: Conn_01x05_Socket; PinHeader_1x05_P2.54mm_Vertical
J_POWER1: Conn_01x04_Pin; PinHeader_1x04_P2.54mm_Vertical
M1: PinHeader_1x03_P2.54mm_Vertical
R1, R2, R4, R5, R14, R16, R17, R19, R20, R21, R22, R23, R24, R30: 10k; R_1206_3216Metric
R3, R12, R15, R18: 1k; R_1206_3216Metric
R6, R7, R8, R9, R10, R11: 100; R_1206_3216Metric
R13, R28: 5k; R_1206_3216Metric
R25, R26, R27: 0.2; R_Axial_DIN0204_L3.6mm_D1.6mm_P1.90mm_Vertical
R29: 1k5; R_1206_3216Metric
U1-IGCM04F60GAXKMA1: IGCM04F60GAXKMA1
U2: LM324; SSOP-14_5.3x6.2mm_P0.65mm
U15-5, U30-15: DC-DC Converter; PinHeader_1x03_P2.54mm_Vertical

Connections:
+3.3V: D1.1 (K), D3.1 (K), D5.1 (K), J3.3.2, R2.2
+5V: D7.1 (K), D9.1 (K), D11.1 (K), D17.2 (A), U2.4 (V+), U15-5.3 (OUT)
+15V: C8.1, C12.1, D16.2 (A), U1-IGCM04F60GAXKMA1.13 (VDD), U15-5.1 (IN), U30-15.3 (OUT)
+30: J_POWER1.2, J_POWER1.3, U30-15.1 (IN)
+30-2: C23.1, D18.2 (A), J_POWER1.1, U1-IGCM04F60GAXKMA1.23
-30: C1.2, C2.2, C3.2, C4.2, C5.2, C6.2, C7.2, C8.2, C12.2, C13.2, C17.2, C18.2, C19.2, C20.2, C21.2, C22.2, C23.2, D2.2 (A), D4.2 (A), D6.2 (A), D8.2 (A), D10.2 (A), D12.2 (A), J3.3.1, J_POWER1.4, R12.1, R15.1, R17.1, R18.1, R25.1, R26.1, R27.1, R28.2, R29.2, R30.2, U1-IGCM04F60GAXKMA1.16 (VSS), U2.11 (V-), U15-5.2 (GND), U30-15.2 (GND)
/ITRIP: C17.1, D13.1 (K), D14.1 (K), D15.1 (K), R4.1, U1-IGCM04F60GAXKMA1.15 (ITRIP)
/NU: R21.1, R24.1, R25.2, U1-IGCM04F60GAXKMA1.19 (NU)
/NU_D: C22.1, D13.2 (A), R24.2
/NV: R20.1, R23.1, R26.2, U1-IGCM04F60GAXKMA1.18 (NV)
/NV_D: C21.1, D14.2 (A), R23.2
/NW: R19.1, R22.1, R27.2, U1-IGCM04F60GAXKMA1.17 (NW)
/NW_D: C20.1, D15.2 (A), R22.2
/UCOP+: C19.1, D11.2 (A), D12.1 (K), R21.2, U2.5 (+)
/UCOP-: R14.1, R18.2, U2.6 (-)
/U_Hi: C2.1, R6.1, U1-IGCM04F60GAXKMA1.7 (HIN(U))
/U_Lo: C5.1, R9.1, U1-IGCM04F60GAXKMA1.10 (LIN(U))
/VCOP+: C18.1, D9.2 (A), D10.1 (K), R20.2, U2.10 (+)
/VCOP-: R5.1, R15.2, U2.9 (-)
/VFO: R2.1, R3.1, R16.1, U1-IGCM04F60GAXKMA1.14 (VFO)
/V_Hi: C3.1, R7.1, U1-IGCM04F60GAXKMA1.8 (HIN(V))
/V_Lo: C6.1, R10.1, U1-IGCM04F60GAXKMA1.11 (LIN(V))
/WCOP+: C13.1, D7.2 (A), D8.1 (K), R19.2, U2.12 (+)
/WCOP-: R1.1, R12.2, U2.13 (-)
/W_Hi: C4.1, R8.1, U1-IGCM04F60GAXKMA1.9 (HIN(W))
/W_Lo: C7.1, R11.1, U1-IGCM04F60GAXKMA1.12 (LIN(W))
CurrentSense U: D5.2 (A), D6.1 (K), J_Current1.3, R14.2, U2.7
CurrentSense V: D3.2 (A), D4.1 (K), J_Current1.4, R5.2, U2.8
CurrentSense W: D1.2 (A), D2.1 (K), J_Current1.5, R1.2, U2.14
Fault: C1.1, J_Current1.1, R3.2
unnamed: D16.1 (K), R28.1
unnamed: D17.1 (K), R29.1
unnamed: D18.1 (K), R30.1
unnamed: M1.1 (U), U1-IGCM04F60GAXKMA1.22 (U)
unnamed: M1.2 (V), U1-IGCM04F60GAXKMA1.21 (V)
unnamed: M1.3 (W), U1-IGCM04F60GAXKMA1.20 (W)
unnamed: C9.2, C14.2, U1-IGCM04F60GAXKMA1.2 (VB(U))
unnamed: C10.2, C15.2, U1-IGCM04F60GAXKMA1.4 (VB(V))
unnamed: C11.2, C16.2, U1-IGCM04F60GAXKMA1.6 (VB(W))
unnamed: C9.1, C14.1, U1-IGCM04F60GAXKMA1.1 (VS(U))
unnamed: C10.1, C15.1, U1-IGCM04F60GAXKMA1.3 (VS(V))
unnamed: C11.1, C16.1, U1-IGCM04F60GAXKMA1.5 (VS(W))
unnamed: R16.2, U2.3 (+)
unnamed: R13.1, R17.2, U2.2 (-)
ShutDown: J3.3.3, R4.2
Temperature Monitor: J_Current1.2, R13.2, U2.1
U-Hi: J_Control1.1, R6.2
U-Lo: J_Control1.4, R9.2
V-Hi: J_Control1.2, R7.2
V-Lo: J_Control1.5, R10.2
W-Hi: J_Control1.3, R8.2
W-Lo: J_Control1.6, R11.2

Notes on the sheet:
MCU IO
Power Supply

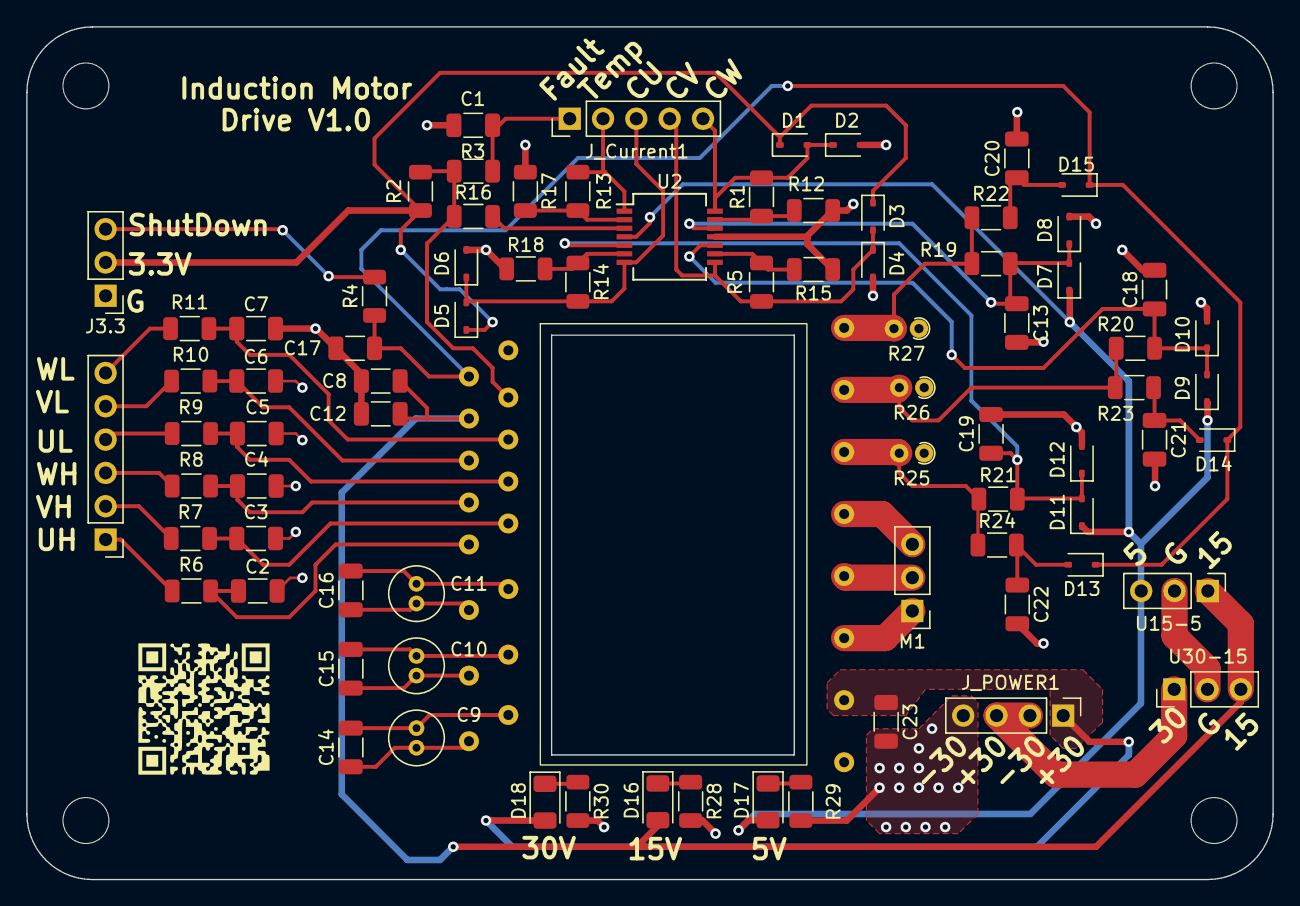
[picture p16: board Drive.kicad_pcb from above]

Board: 2 copper layers, 95.0 x 65.0 mm, 84 parts (0 on the bottom side), 52 nets.

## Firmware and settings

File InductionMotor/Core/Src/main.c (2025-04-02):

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
/* Includes ------------------------------------------------------------------*/
#include "main.h"

/* USER CODE BEGIN Includes */
#include <stdio.h>
#include <string.h>
#include <arm_math.h>
#include <stdlib.h>
#include "Sbus.h"
#include "Encoder.h"
#include "SineWave.h"
#include "PID.h"
#include "string.h"
/* USER CODE END Includes */

/* USER CODE BEGIN PTD */
typedef enum{
	Off=0,
	Forward=1,
	Reverse=2
}StateMachine;
/* USER CODE END PTD */

ADC_HandleTypeDef hadc1;
DMA_HandleTypeDef hdma_adc1;

TIM_HandleTypeDef htim1;
TIM_HandleTypeDef htim3;
TIM_HandleTypeDef htim10;

UART_HandleTypeDef huart1;
UART_HandleTypeDef huart2;
DMA_HandleTypeDef hdma_usart1_rx;

/* USER CODE BEGIN PV */
tsbus receivedSBUS;
uint32_t PreviousStepChangeTime=0;
uint32_t FrequencyChangeTime=0;
uint32_t ScreenUpdateTime=0;
int Step=1;
StateMachine State=Off;
StateMachine PreviousState=Forward;
encoder_data Encoder;
int32_t EncoderMeasureTime=0;
int Enable=0;
int ToggleState=0;
int UpdateState = 0;
uint32_t  RequestedFrequency = 0;
StateMachine Direction=0;
ST_SineWave SineWave;
int FiftyMicroSecond;
PID_Controller PID;
uint16_t ADCRawValues[7];
uint8_t ADCReady=0;
float Potentiameter=0;
float MCUTemp=0;
float DriveTemp =0,Current_U =0,Current_V =0,Current_W =0,Current_N =0;
uint8_t PotZeroed =0;
/* USER CODE END PV */

void SystemClock_Config(void);
static void MX_GPIO_Init(void);
static void MX_DMA_Init(void);
static void MX_USART2_UART_Init(void);
static void MX_TIM10_Init(void);
static void MX_TIM1_Init(void);
static void MX_ADC1_Init(void);
static void MX_USART1_UART_Init(void);
static void MX_TIM3_Init(void);
/* USER CODE BEGIN PFP */
void HAL_TIM_IC_CaptureCallback(TIM_HandleTypeDef *htim){
	if (htim->Instance == TIM3){
		Encoder.EncoderValue = __HAL_TIM_GET_COUNTER(htim);
	}
}
void HAL_TIM_PeriodElapsedCallback(TIM_HandleTypeDef *htim){
	if (htim->Instance == TIM10){
		FiftyMicroSecond=1;
	}
}
void HAL_UART_RxCpltCallback(UART_HandleTypeDef *huart){
	if (huart == &huart2){
		ParseSBUS(&receivedSBUS);
	}
}
void HAL_ADC_ConvCpltCallback(ADC_HandleTypeDef *hadc){
	ADCReady=1;
}
void HAL_GPIO_EXTI_Callback(uint16_t GPIO_Pin)
{
  if(GPIO_Pin == GPIO_PIN_0){
	  ToggleState=1;
  }
  if(GPIO_Pin== GPIO_PIN_2){
	  Enable=0;
  }
}
/* USER CODE END PFP */

/**
  * @brief  The application entry point.
  * @retval int
  */
int main(void)
{

  /* MCU Configuration--------------------------------------------------------*/

  /* Reset of all peripherals, Initializes the Flash interface and the Systick. */
  HAL_Init();

  /* Configure the system clock */
  SystemClock_Config();

  /* Initialize all configured peripherals */
  MX_GPIO_Init();
  MX_DMA_Init();
  MX_USART2_UART_Init();
  MX_TIM10_Init();
  MX_TIM1_Init();
  MX_ADC1_Init();
  MX_USART1_UART_Init();
  MX_TIM3_Init();
  /* USER CODE BEGIN 2 */
//  HAL_TIM_PWM_Start(&htim1, TIM_CHANNEL_1);
//  HAL_TIMEx_PWMN_Start(&htim1, TIM_CHANNEL_1);
//  HAL_TIM_PWM_Start(&htim1, TIM_CHANNEL_2);
//  HAL_TIMEx_PWMN_Start(&htim1, TIM_CHANNEL_2);
//  HAL_TIM_PWM_Start(&htim1, TIM_CHANNEL_3);
//  HAL_TIMEx_PWMN_Start(&htim1, TIM_CHANNEL_3);
  TIM1->BDTR|=1<<15;//Enables timer 1 outputs that are set in CCER and CCER register
  TIM1->CR1|=1<<0;//Enables the counting in timer 1
  HAL_TIM_Base_Start_IT(&htim10);
  HAL_TIM_Encoder_Start_IT(&htim3, TIM_CHANNEL_ALL);
  HAL_UART_Receive_DMA(&huart2, &receivedSBUS.ReceivedData[0], SBUS_LEN);
  HAL_ADC_Start_DMA(&hadc1, (uint16_t*) ADCRawValues, 7);
  /* USER CODE END 2 */

  /* Infinite loop */
  /* USER CODE BEGIN WHILE */
  HAL_UART_Transmit_IT(&huart2, "Induction Driver V2.0\n", strlen("Induction Driver V2.0\n"));
  HAL_GPIO_WritePin(LD1_GPIO_Port, LD1_Pin, 1);
  HAL_Delay(500);
  HAL_GPIO_WritePin(LD2_GPIO_Port, LD2_Pin, 1);
  HAL_GPIO_WritePin(LD1_GPIO_Port, LD1_Pin, 0);
  HAL_Delay(500);
  HAL_GPIO_WritePin(LD3_GPIO_Port, LD3_Pin, 1);
  HAL_GPIO_WritePin(LD2_GPIO_Port, LD2_Pin, 0);
  HAL_Delay(500);
  HAL_GPIO_WritePin(LD3_GPIO_Port, LD3_Pin, 0);
  HAL_Delay(500);

  SineWave.WaveFrequency=MIN_FREQUENCY;
  SineWave.FrequencyA=MIN_FREQUENCY;
  SineWave.FrequencyB=MIN_FREQUENCY;
  SineWave.FrequencyC=MIN_FREQUENCY;


  PID.ControlMode=Velocity;
  PID.Kp=5;
  PID.Ki=0;
  PID.Kd=0;
  PID.dt=10;
  PID.integral=0;
  PID.min_output= 5;
  PID.max_output= 55;
  PID.min_Integral= 5;
  PID.max_Integral= 55;
  PID.output=10;
  PID.target=100;

  HAL_GPIO_WritePin(ShutDown_GPIO_Port, ShutDown_Pin, 0);

  while (1)
  {
	  if(ADCReady==1){
		  ADCReady=0;
		  DriveTemp 	= ADCRawValues[0];
		  Current_U 	= ADCRawValues[1];
		  Current_V 	= ADCRawValues[2];
		  Current_W 	= ADCRawValues[3];
		  Current_N 	= ADCRawValues[4];
		  Potentiameter	= ADCRawValues[5] *100.0/4096.0;
		  MCUTemp		= ADCRawValues[6];
	  }
	  if (Potentiameter<5.0) PotZeroed=1;
	  (PotZeroed==1)? (HAL_GPIO_WritePin(LD1_GPIO_Port,LD1_Pin,0)): (HAL_GPIO_WritePin(LD1_GPIO_Port, LD1_Pin, 1));

	  if (PotZeroed==1 && Potentiameter >=5.0 ){
		  RequestedFrequency= Potentiameter * 60.0/100.0;
		  if (State==Off) ToggleState=1;
	  }

	  //V/F for 208V 60Hz motor under test:
	  double Voltage = ( SineWave.WaveFrequency * (208.0/60.0) ) * 10.0;
	  if ( Voltage < 600) Voltage=600;
	  else if (Voltage >= 1000) Voltage = 1000;
	  SineWave.VoltageAmplitude= trunc(Voltage);
	  //Calculate RPM
	  //read every 10ms so *100*60 to be per minute
	  //1024*4 pulse / revolution on encoder
	  //Pully ratio 20:50
	  //GetEncoderValue(&Encoder); 	//Obsolete since not using GPIO and using timer to capture encoder value
	  if ((HAL_GetTick()-EncoderMeasureTime)>=10){
		  Encoder.SpeedRPM=(Encoder.EncoderValue-Encoder.PreviousEncoderValue)*((60*100)*20)/(1024*4*50);
		  Encoder.PreviousEncoderValue=Encoder.EncoderValue;
		  //PID Speed Control
		  updatePID(&PID, fabs(Encoder.SpeedRPM));
		  //RequestedFrequency=PID.output;
		  //Report Speed on UART
		  char msg[500];
		  uint32_t RequestedRPM=RequestedFrequency*1735/60;
		  uint32_t Slip= RequestedRPM - fabs(Encoder.SpeedRPM);
		  int len= sprintf(msg,"%.2f, U=%.2f, V=%.2f, W=%.2f, %.2f, %.2f, %.2f\n",DriveTemp,Current_U,Current_V,Current_W,Current_N,Potentiameter ,MCUTemp);
		  HAL_UART_Transmit_IT(&huart2, msg, len);
		  EncoderMeasureTime= HAL_GetTick();
	  }
	  //enable/disable by push button
	  if (ToggleState){
		  if (State==Forward || State==Reverse) State=Off;
		  else if (State==Off && PreviousState==Reverse) State=PreviousState=Forward;
		  else if (State==Off && PreviousState==Forward) State=PreviousState=Reverse;
		  ToggleState=0;
	  }
	  //State Machine
	  switch(State){
	  	  case	Off:
	  		  Enable=0;
	  		  break;
	  	  case Forward:
	  		  Enable=1;
	  		  Direction=Forward;
	  		  break;
	  	  case Reverse:
	  		  Enable=1;
	  		  Direction=Reverse;
	  		  break;
	  }
	  //Run motor if enabled
	  Direction=Forward;//testing forward for now
	  RequestedFrequency=30;//testing fixed frequency
	  if(Enable && State!= Off && PotZeroed && Potentiameter >10.0){
		  //Generating Sinusoidal PWM
		  GenerateSine(&SineWave, &FiftyMicroSecond);
		  //Ramp Frequency
		  if ((HAL_GetTick()-FrequencyChangeTime)>=200 && RequestedFrequency != SineWave.WaveFrequency){
			  if (RequestedFrequency > SineWave.WaveFrequency) SineWave.WaveFrequency++;
			  else if (RequestedFrequency < SineWave.WaveFrequency) SineWave.WaveFrequency--;
			  FrequencyChangeTime= HAL_GetTick();
		  }
	  }
	  //if not enabled then stop everything
	  else {
		  SineWave.PhaseA	=SineWave.PhaseB	=SineWave.PhaseC	=0;
		  SineWave.Time	=0;
		  SineWave.WaveFrequency=MIN_FREQUENCY;
	  }
	  //send PWM values out
	  if(Direction==Forward){
		  if (SineWave.PhaseA > 0){
			  TIM1->CCER &= ~(1<<2);
			  TIM1->CCER |=   1<<0;
			  TIM1->CCR1  = SineWave.PhaseA;
		  }
		  else{
			  TIM1->CCER &= ~(1<<0);
			  TIM1->CCER |=   1<<2;
			  TIM1->CCR1  = -1*SineWave.PhaseA;
		  }
		  if (SineWave.PhaseB > 0){
			  TIM1->CCER &= ~(1<<6);
			  TIM1->CCER |=   1<<4;
			  TIM1->CCR2  = SineWave.PhaseB;
		  }
		  else{
			  TIM1->CCER &= ~(1<<4);
			  TIM1->CCER |=   1<<6;
			  TIM1->CCR2  = -1*SineWave.PhaseB;
		  }
		  if (SineWave.PhaseC > 0){
			  TIM1->CCER &= ~(1<<10);
			  TIM1->CCER |=   1<<8;
			  TIM1->CCR3  = SineWave.PhaseC;
		  }
		  else{
			  TIM1->CCER &= ~(1<<8);
			  TIM1->CCER |=   1<<10;
			  TIM1->CCR3  = -1*SineWave.PhaseC;
		  }
	  }
	  else if (Direction==Reverse){
		  if (SineWave.PhaseA > 0){
			  TIM1->CCER &= ~(1<<2);
			  TIM1->CCER |=   1<<0;
			  TIM1->CCR2  = SineWave.PhaseA;
		  }
		  else{
			  TIM1->CCER &= ~(1<<0);
			  TIM1->CCER |=   1<<2;
			  TIM1->CCR2  = -1*SineWave.PhaseA;
		  }
		  if (SineWave.PhaseB > 0){
			  TIM1->CCER &= ~(1<<6);
			  TIM1->CCER |=   1<<4;
			  TIM1->CCR1  = SineWave.PhaseB;
		  }
		  else{
			  TIM1->CCER &= ~(1<<4);
			  TIM1->CCER |=   1<<6;
			  TIM1->CCR1  = -1*SineWave.PhaseB;
		  }
		  if (SineWave.PhaseC > 0){
			  TIM1->CCER &= ~(1<<10);
			  TIM1->CCER |=   1<<8;
			  TIM1->CCR3  = SineWave.PhaseC;
		  }
		  else{
			  TIM1->CCER &= ~(1<<8);
			  TIM1->CCER |=   1<<10;
			  TIM1->CCR3  = -1*SineWave.PhaseC;
		  }
	  }
	  else{ TIM1->CCR1 = TIM1->CCR2 = TIM1->CCR3 = 0; }
    /* USER CODE END WHILE */

    /* USER CODE BEGIN 3 */
  }
  /* USER CODE END 3 */
}

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


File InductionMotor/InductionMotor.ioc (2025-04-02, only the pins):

Mcu.UserName=STM32F411RETx
PA1.GPIO_Label=Drive_Temp
PA1.Signal=ADCx_IN1
PA10.Signal=S_TIM1_CH3
PA13.GPIO_Label=TMS
PA13.Signal=SYS_JTMS-SWDIO
PA14.GPIO_Label=TCK
PA14.Signal=SYS_JTCK-SWCLK
PA15.Signal=USART1_TX
PA2.GPIO_Label=USART_TX
PA2.Signal=USART2_TX
PA3.GPIO_Label=USART_RX
PA3.Signal=USART2_RX
PA6.GPIO_Label=I_U
PA6.Signal=ADCx_IN6
PA7.GPIO_Label=I_V
PA7.Signal=ADCx_IN7
PA8.Signal=S_TIM1_CH1
PA9.Signal=S_TIM1_CH2
PB0.GPIO_Label=I_W
PB0.Signal=ADCx_IN8
PB1.GPIO_Label=I_N
PB1.Signal=ADCx_IN9
PB13.Signal=TIM1_CH1N
PB14.Signal=TIM1_CH2N
PB15.Signal=TIM1_CH3N
PB3.GPIO_Label=SWO
PB3.Signal=SYS_JTDO-SWO
PB7.Signal=USART1_RX
PC0.GPIO_Label=PB1_INT
PC0.Signal=GPXTI0
PC1.GPIO_Label=ShutDown
PC1.Signal=GPIO_Output
PC10.GPIO_Label=LD1
PC10.Signal=GPIO_Output
PC11.GPIO_Label=LD2
PC11.Signal=GPIO_Output
PC12.GPIO_Label=LD3
PC12.Signal=GPIO_Output
PC14-OSC32_IN.Signal=RCC_OSC32_IN
PC15-OSC32_OUT.Signal=RCC_OSC32_OUT
PC2.GPIO_Label=DriveFault_INT
PC2.Signal=GPXTI2
PC3.GPIO_Label=Potentiameter
PC3.Signal=ADCx_IN13
PC6.Signal=S_TIM3_CH1
PC7.Signal=S_TIM3_CH2

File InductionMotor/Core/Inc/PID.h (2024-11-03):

enum Mode{
	Velocity = 0,
	Position = 1,
	Torque = 2,
};

typedef struct{
	enum Mode ControlMode;
    double Kp;
    double Ki;
    double Kd;
    double min_output;
    double max_output;
    double min_Integral;
    double max_Integral;
    double target;
    double CurrentError;
    double prev_error;
    double integral;
    double dt; //sample time in msec
    double output;
}PID_Controller;
#define ENCODER_RESOLUTION 1024
#define PWM_MAXVALUE	1000


void updatePID(PID_Controller* pid, double current);

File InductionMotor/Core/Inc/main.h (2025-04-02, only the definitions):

#define PB1_INT_Pin GPIO_PIN_0
#define PB1_INT_GPIO_Port GPIOC
#define PB1_INT_EXTI_IRQn EXTI0_IRQn
#define ShutDown_Pin GPIO_PIN_1
#define ShutDown_GPIO_Port GPIOC
#define DriveFault_INT_Pin GPIO_PIN_2
#define DriveFault_INT_GPIO_Port GPIOC
#define DriveFault_INT_EXTI_IRQn EXTI2_IRQn
#define Potentiameter_Pin GPIO_PIN_3
#define Potentiameter_GPIO_Port GPIOC
#define Drive_Temp_Pin GPIO_PIN_1
#define Drive_Temp_GPIO_Port GPIOA
#define USART_TX_Pin GPIO_PIN_2
#define USART_TX_GPIO_Port GPIOA
#define USART_RX_Pin GPIO_PIN_3
#define USART_RX_GPIO_Port GPIOA
#define I_U_Pin GPIO_PIN_6
#define I_U_GPIO_Port GPIOA
#define I_V_Pin GPIO_PIN_7
#define I_V_GPIO_Port GPIOA
#define I_W_Pin GPIO_PIN_0
#define I_W_GPIO_Port GPIOB
#define I_N_Pin GPIO_PIN_1
#define I_N_GPIO_Port GPIOB
#define TMS_Pin GPIO_PIN_13
#define TMS_GPIO_Port GPIOA
#define TCK_Pin GPIO_PIN_14
#define TCK_GPIO_Port GPIOA
#define LD1_Pin GPIO_PIN_10
#define LD1_GPIO_Port GPIOC
#define LD2_Pin GPIO_PIN_11
#define LD2_GPIO_Port GPIOC
#define LD3_Pin GPIO_PIN_12
#define LD3_GPIO_Port GPIOC
#define SWO_Pin GPIO_PIN_3
#define SWO_GPIO_Port GPIOB

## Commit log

2024-01-07 adds circuit diagram
    [Drive.kicad_pcb, Drive.kicad_sch]
2024-01-12 adds code for motor to run
    [Drive.kicad_sch]
2024-01-13 adds encoder
    [Encoder Bracket.SLDPRT, Encoder Shaft.SLDPRT, motor pully.SLDPRT]
2024-01-16 adds oled screen
    [Encoder.SLDASM, tensioner.SLDPRT]
2024-01-21 adds circuit diagram and pcb
    [Drive.kicad_pcb, Drive.kicad_sch]
2024-01-22 design bug fix
    [Drive.kicad_pcb]
2024-01-26 Motor Running
2024-02-12 testing with PCB
    [Drive.kicad_pcb, Drive.kicad_sch, base for board.SLDPRT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]
2024-05-09 added forward reverse state machine
    [InductionMotor.ioc, main.c]
2024-05-15 adds encoder as an EXTI
2024-05-27 made TIM4 a slave of TIM3 and also fixed the freaking 50usec bug!!!!!!!!!!!!!!!!!!!!!!! Sine wave now continues
    [InductionMotor.ioc, main.c]
2024-05-29 put encoder back on timer 2
2024-05-29 Reporting speed and slip on uart to monitor on PC
    [InductionMotor.ioc, main.c]
2024-10-28 mcu swapped with a new one and timers back in order
    [InductionMotor.ioc, main.c, main.h]
2024-11-03 finally smooth current shape
2024-12-28 drive V2 pcb designed
    [AC_Driver_V2-B_Cu.gbr, AC_Driver_V2-B_Mask.gbr, AC_Driver_V2-B_Paste.gbr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]
2025-01-18 V2 tested and working - WIP
    [AC_Driver_V2.kicad_pcb, AC_Driver_V2.kicad_sch]
2025-01-19 corrects receiver pins
    [AC_Driver_V2.kicad_pcb, AC_Driver_V2.kicad_sch]
2025-01-19 adds potentiameter to control the speed
    [AC_Driver_V2.kicad_pcb, AC_Driver_V2.kicad_sch]
2025-04-02 latest sync
    [AC_Driver_V2_1.kicad_pcb, AC_Driver_V2_1.kicad_sch, InductionMotor Debug.cfg]

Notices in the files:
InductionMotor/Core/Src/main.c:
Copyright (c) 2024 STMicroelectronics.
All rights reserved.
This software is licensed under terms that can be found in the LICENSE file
